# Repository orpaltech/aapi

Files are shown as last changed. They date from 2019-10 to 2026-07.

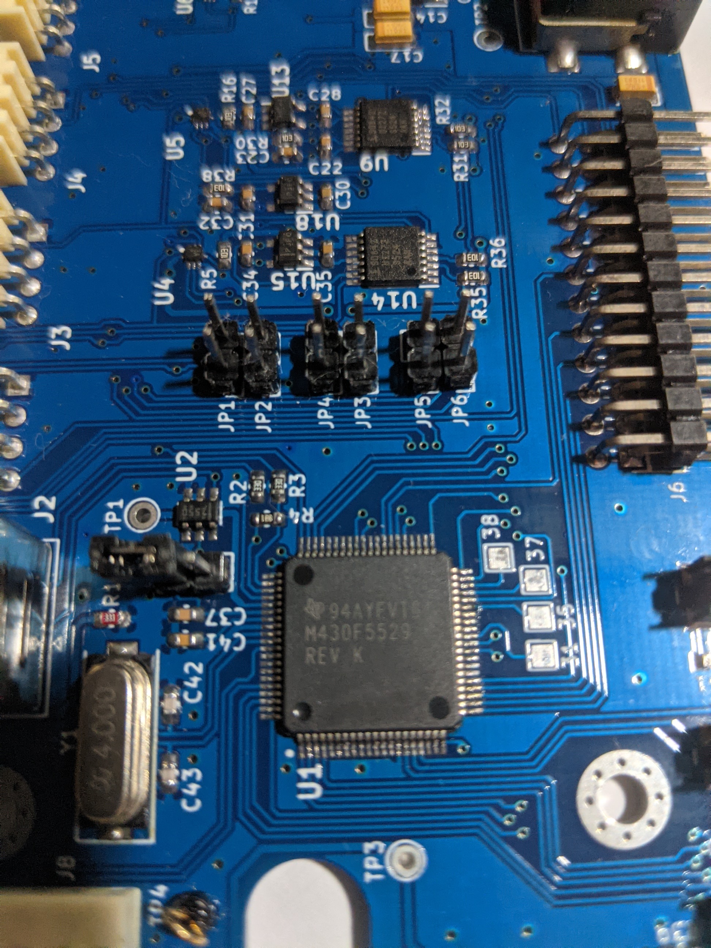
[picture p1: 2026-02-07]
hardware/images/EV2400/PXL_20260128_093434642.jpg

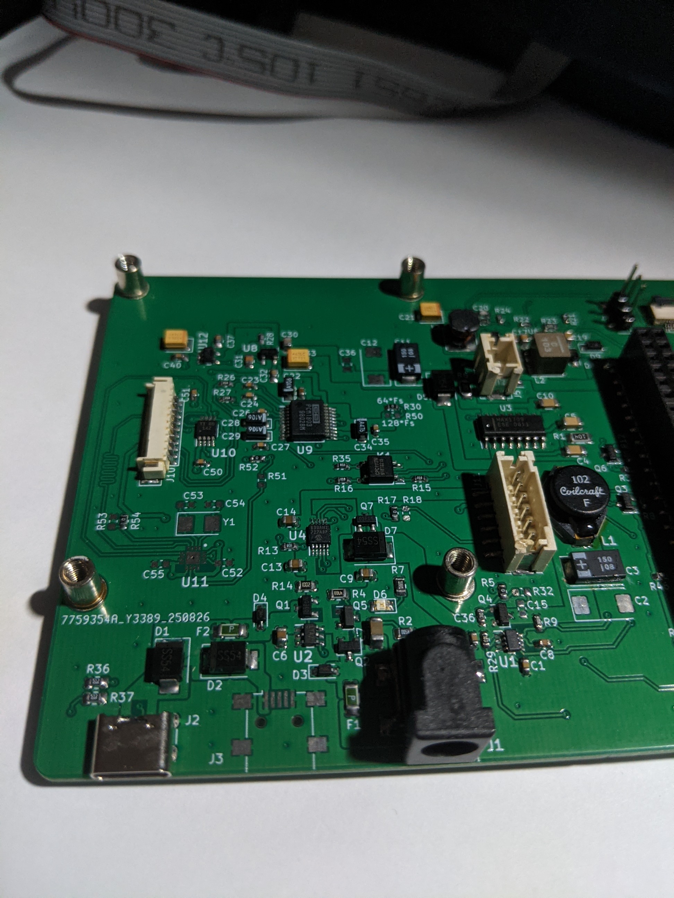
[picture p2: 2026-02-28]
hardware/images/v4.2/PXL_20260226_131540417.jpg

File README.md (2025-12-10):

ORPAL AA-PI
==============

Antenna analyzer project for portable Linux-based devices. 
The current hardware implementation is based on BananaPi M2-Magic SBC (Allwinner R16).

Version 4.3

Based on the Yuri Kuchura's EU1KY_AA_V3 https://github.com/EU1KY/eu1ky_aa_v3

Build
==============

The build process depends on the platform you have chosen. Currently the AA-PI software is managed by repository https://github.com/orpaltech/armlinux.

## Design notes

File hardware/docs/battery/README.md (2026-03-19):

# bq34z100-g1 + SN74HC164 Battery Gauge Setup

Hardware: 1S Li-ion (3800mAh), MCP73833 Charger (500/1000mA), 7-LED Display via Shift Register.

## 1. Initial Data Flash Configuration
Before starting, set these key parameters in **bqStudio**:

### 7-LED Display (SN74HC164)
*   **LED_Comm Configuration**: `0x63` (7 LEDs, Port Expander Mode, Button Trigger).
*   **Number of LEDs**: `7` (Verify in Configuration subclass).
*   **LED Hold Time**: `4` seconds.

### Gauge Thresholds
*   **Design Capacity**: `3800` mAh
*   **Design Energy**: `14060` mWh (3.7V * 3800)
*   **Taper Current**: `85` mA (Safe for 500mA/1000mA charging modes).
*   **Quit Current**: `20` mA (Must be lower than Taper).
*   **Dsg Relax Time**: `60` s (Speeds up OCV detection).
*   **Terminate Voltage**: `3200` mV (Set ~100mV above SBC/Boost cutoff).

## 2. Chemistry ID (GPCCHEM)
Do not use generic IDs. Follow this log sequence for the TI matching tool:
1.  Charge to full (Wait for **FC** bit).
2.  Rest **2 hours** (Wait for **OCVTAKEN=1**).
3.  Discharge at **C/10** (approx. 380mA - 500mA, I used Raspberry Pi 3 A+ with ESP32 HostedNG) until **Terminate Voltage**.
4.  Rest **5 hours** (Wait for **OCVTAKEN=1**).
5.  Zip the log and upload to [TI GPC Tool](https://www.ti.com). Program the resulting ID (e.g., `0x3230`) into the gauge.

## 3. Calibration
*   **Voltage**: Calibrate against a high-quality multimeter (Crucial for Qmax accuracy).
*   **Current**: Calibrate with a known stable load (e.g., 500mA).
*   **Temperature**: Set **TEMPS bit = 1** (External) for NTC thermistor.

## 4. The Learning Cycle (04 -> 05 -> 06)
1.  **IT_ENABLE**: Send command `0x0021`. **Update Status** should be `04`.
2.  **Empty Rest**: Wait at 0mA until **OCVTAKEN=1**.
3.  **Charge to Full**: Charge until **FC** bit is Red.
4.  **Full Rest**: Unplug charger. Wait **2 hours** until **OCVTAKEN=1**.
5.  **Discharge**: Run SBC load (500-600mA) until it shuts down.
6.  **Final Rest**: Wait **5 hours**.
    *   **Update Status 05**: Qmax updated.
    *   **Update Status 06**: Ra Table (Resistance) updated.

## 5. Troubleshooting
*   **OCVTAKEN won't set?** Check that **Current** is exactly `0mA`. If it flickers, re-calibrate CC Offset.
*   **Qmax too high?** Usually caused by starting a cycle on a non-rested battery or poor voltage calibration. Manually reset Qmax to 3800 and Update Status to 04 if it drifts.
*   **LEDs don't light?** Check wiring to SDA/SCL and ensure **VEN** pin is pulsed to Ground.

## 6. Dynamic Rebound Handling
To prevent the Learning Cycle from failing due to voltage rebound, use Cell Terminate Voltage (e.g., 3400mV) combined with Cell Term V Delta (e.g., 200mV). This creates a "Resting Empty" window (up to 3600mV) that accounts for the battery's natural spring-back after the SBC load is removed.

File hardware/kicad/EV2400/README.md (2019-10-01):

This is my implementation of the Texas Instruments EV2400 Interface board. The board datasheet is located here http://www.ti.com/lit/ug/sluu446c/sluu446c.pdf

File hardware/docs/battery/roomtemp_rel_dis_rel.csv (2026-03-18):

Sample | DateTime | ElapsedTime | Voltage | Current | Temperature | LogRowTime(ms) | LogStatus
1 | 2025-05-29 02:36:37 | 10.000 | 4189 | 0 | 27.0 | 46 | SUCCESS
2 | 2025-05-29 02:36:48 | 21.349 | 4189 | 0 | 27.0 | 39 | SUCCESS
3 | 2025-05-29 02:36:57 | 30.001 | 4189 | 0 | 27.0 | 44 | SUCCESS
4 | 2025-05-29 02:37:08 | 41.346 | 4189 | 0 | 27.0 | 45 | SUCCESS
5 | 2025-05-29 02:37:17 | 50.001 | 4189 | 0 | 27.0 | 44 | SUCCESS
6 | 2025-05-29 02:37:28 | 61.345 | 4189 | 0 | 27.0 | 44 | SUCCESS
7 | 2025-05-29 02:37:37 | 70.003 | 4189 | 0 | 27.0 | 42 | SUCCESS
8 | 2025-05-29 02:37:48 | 81.345 | 4189 | 0 | 27.0 | 44 | SUCCESS
9 | 2025-05-29 02:37:57 | 90.004 | 4189 | 0 | 27.0 | 44 | SUCCESS
10 | 2025-05-29 02:38:08 | 101.361 | 4189 | 0 | 27.0 | 46 | SUCCESS
11 | 2025-05-29 02:38:17 | 110.005 | 4189 | 0 | 27.0 | 41 | SUCCESS
12 | 2025-05-29 02:38:28 | 121.377 | 4189 | 0 | 27.0 | 44 | SUCCESS
13 | 2025-05-29 02:38:37 | 130.006 | 4189 | 0 | 27.0 | 40 | SUCCESS
14 | 2025-05-29 02:38:48 | 141.361 | 4189 | 0 | 27.0 | 46 | SUCCESS
15 | 2025-05-29 02:38:57 | 150.007 | 4189 | 0 | 27.0 | 40 | SUCCESS
16 | 2025-05-29 02:39:08 | 161.362 | 4189 | 0 | 27.0 | 44 | SUCCESS
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

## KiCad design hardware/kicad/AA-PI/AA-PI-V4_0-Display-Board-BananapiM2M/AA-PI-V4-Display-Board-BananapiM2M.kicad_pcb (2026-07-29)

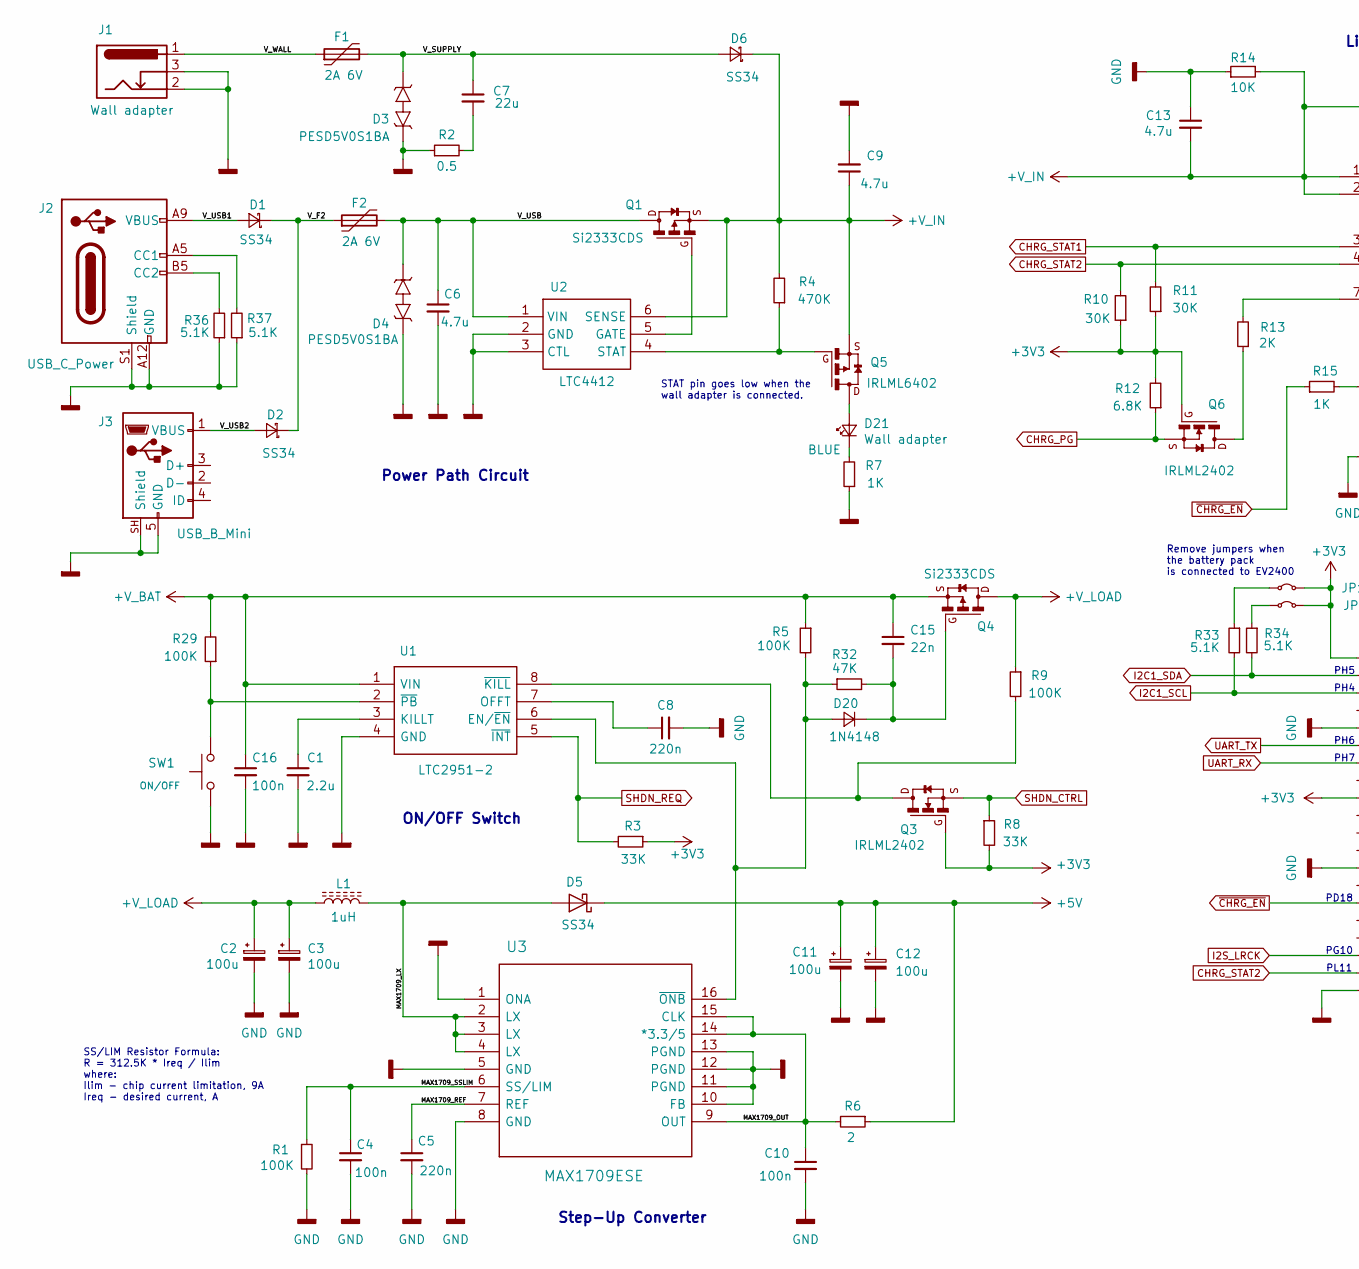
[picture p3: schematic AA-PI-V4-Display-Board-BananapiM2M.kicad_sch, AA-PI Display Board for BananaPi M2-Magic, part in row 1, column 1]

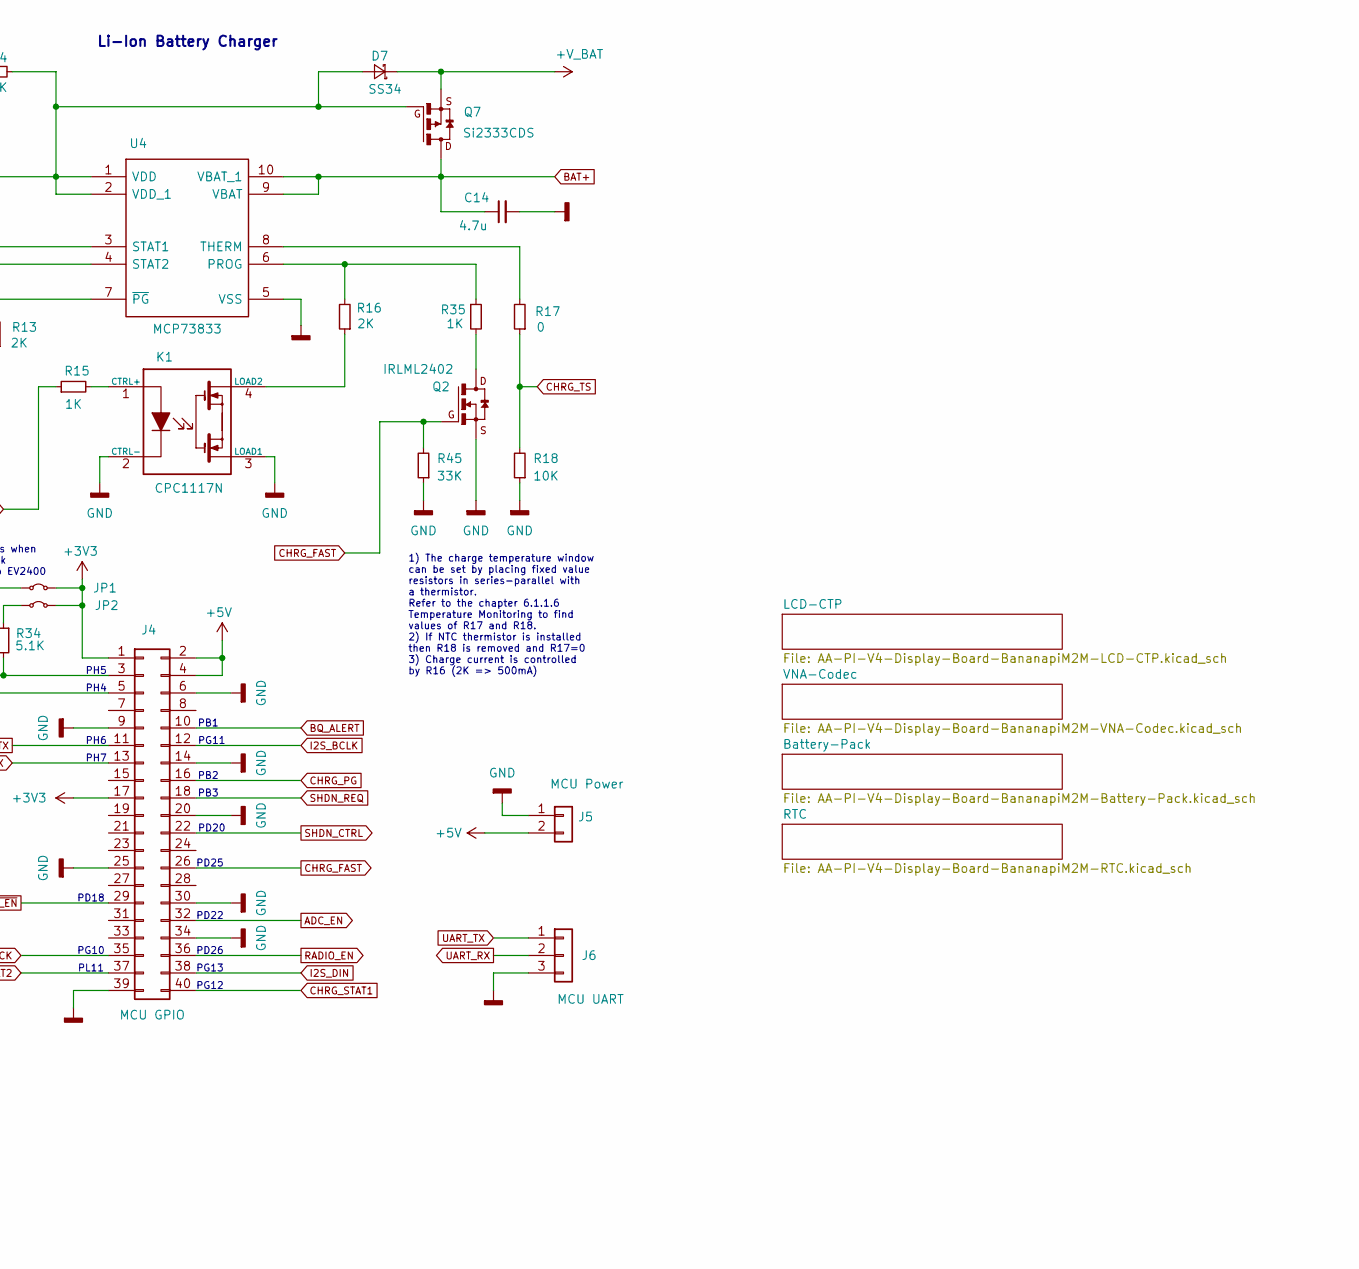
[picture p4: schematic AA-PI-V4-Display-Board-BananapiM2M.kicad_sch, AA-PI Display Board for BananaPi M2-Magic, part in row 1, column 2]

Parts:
C1: 2.2u; C_0603_1608Metric
C2, C3, C11, C12: 100u; CP_EIA-7343-31_Kemet-D
C4, C10: 100n; C_1206_3216Metric
C5: 220n; C_1206_3216Metric
C6, C9, C13, C14: 4.7u; C_0805_2012Metric
C7: 22u; C_1206_3216Metric
C8: 220n; C_0603_1608Metric
C15: 22n; C_0603_1608Metric
C16: 100n; C_0603_1608Metric
D1, D2, D5, D6, D7: SS34; D_SMA
D3, D4: PESD5V0S1BA; D_SOD-323_HandSoldering
D20: 1N4148; D_SOD-323_HandSoldering
D21: Wall adapter; LED_0805_2012Metric_Pad1.15x1.40mm_HandSolder
F1, F2: 2A 6V; Fuse_1206_3216Metric_Pad1.42x1.75mm_HandSolder
J1: Wall adapter; DC-050-SMD-Power-Jack
J2: USB_C_Power; USB_C_Receptacle_GCT_USB4125-xx-x_6P_TopMnt_Horizontal
J3: USB_B_Mini; USB_Mini-B_Lumberg_2486_01_Horizontal
J4: MCU GPIO; PinSocket_2x20_P2.54mm_Vertical_SMD
J5: MCU Power; JST_PH_B2B-PH-SM4-TB_1x02-1MP_P2.00mm_Vertical
J6: MCU UART; PinHeader_1x03_P2.54mm_Vertical_SMD_Pin1Left
JP1, JP2: Jumper_2_Small_Bridged; PinHeader_2x01_P2.00mm_Vertical_SMD
K1: CPC1117N; SOP254P610X218-4N; Manufacturer_Part_Number CPC1117N
L1: 1uH; COILCRAFT_DO3316P102MLB
Q1, Q4, Q7: Si2333CDS; SOT-23
Q2, Q3, Q6: IRLML2402; SOT-23
Q5: IRLML6402; SOT-23
R1: 100K; R_1206_3216Metric
R2: 0.5; R_0805_2012Metric
R3, R8, R45: 33K; R_0603_1608Metric
R4: 470K; R_0805_2012Metric
R5, R9, R29: 100K; R_0603_1608Metric
R6: 2; R_1206_3216Metric
R7: 1K; R_0805_2012Metric
R10, R11: 30K; R_0603_1608Metric
R12: 6.8K; R_0603_1608Metric
R13, R16: 2K; R_0603_1608Metric
R14: 10K; R_0805_2012Metric
R15, R35: 1K; R_0603_1608Metric
R17: 0; R_0603_1608Metric
R18: 10K; R_0603_1608Metric
R32: 47K; R_0603_1608Metric
R33, R34: 5.1K; R_0603_1608Metric
R36, R37: 5.1K; R_0805_2012Metric
SW1: ON/OFF; SW_SPST_CK_RS282G05A3
U1: LTC2951-2; SOT65P280X100-8N; Manufacturer_Part_Number LTC2951CTS8-1#TRMPBF
U2: LTC4412; SOT95P280X100-6N; Manufacturer_Part_Number LTC4412ES6#TRMPBF
U3: MAX1709ESE; SOIC-16_3.9x9.9mm_P1.27mm
U4: MCP73833; SOP50P490X110-10N; Manufacturer_Part_Number MCP73833-FCI/UN

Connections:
+3V3: J4.1, J4.17, JP1.2 (B), JP2.2 (B), Q3.1 (G), Q6.1 (G), R3.1, R8.2, R10.1, R11.1, R12.2; also elsewhere on the board
+5V: C11.1, C12.1, D5.1 (K), J4.2, J4.4, J5.2, R6.1; also elsewhere on the board
+V_BAT: C15.1, C16.1, D7.1 (K), Q4.2 (S), Q7.2 (S), R5.1, R29.2, U1.1 (VIN)
+V_IN: C9.1, C13.2, D6.1 (K), D7.2 (A), Q1.2 (S), Q5.2 (S), Q7.1 (G), R4.2, R14.2, U2.6 (SENSE), U4.1 (VDD), U4.2 (VDD_1)
+V_LOAD: C2.1, C3.1, L1.1, Q4.3 (D), R9.1
/MAX1709_LX: D5.2 (A), L1.2, U3.2 (LX), U3.3 (LX), U3.4 (LX)
/MAX1709_OUT: C10.1, R6.2, U3.9 (OUT), U3.14 (*3.3/5), U3.15 (CLK)
/MAX1709_REF: C5.1, U3.7 (REF)
/MAX1709_SSLIM: C4.1, R1.1, U3.6 (SS/LIM)
/V_F2: D1.1 (K), D2.1 (K), F2.1
/V_SUPPLY: C7.1, D3.2, D6.2 (A), F1.2
/V_USB: C6.1, D4.2, F2.2, Q1.3 (D), U2.1 (VIN)
/V_USB1: D1.2 (A), J2.A9 (VBUS), J2.B9 (VBUS)
/V_USB2: D2.2 (A), J3.1 (VBUS)
/V_WALL: F1.1, J1.1
ADC_EN: J4.32; also elsewhere on the board
BAT+: C14.1, Q7.3 (D), U4.9 (VBAT), U4.10 (VBAT_1); also elsewhere on the board
BQ_ALERT: J4.10; also elsewhere on the board
CHRG_FAST: J4.26, Q2.1 (G), R45.2
CHRG_PG: J4.16, Q6.2 (S), R12.1
CHRG_STAT1: J4.40, R11.2, U4.3 (STAT1)
CHRG_STAT2: J4.37, R10.2, U4.4 (STAT2)
CHRG_TS: R17.1, R18.2; also elsewhere on the board
GND: C1.2, C2.2, C3.2, C4.2, C5.2, C6.2, C8.2, C9.2, C10.2, C11.2, C12.2, C13.1, C14.2, C16.2, D3.1, D4.1, J1.2, J1.3, J2.A12 (GND), J2.B12 (GND), J2.S1 (Shield), J3.5 (GND), J3.SH (Shield), J4.6, J4.9, J4.14, J4.20, J4.25, J4.30, J4.34, J4.39, J5.1, J6.3, K1.2 (CTRL-), K1.3 (LOAD1), Q2.2 (S), R1.2, R2.1, R7.1, R14.1, R18.1, R36.1, R37.1, R45.1, SW1.1, U1.4 (GND), U2.2 (GND), U2.3 (CTL), U3.1 (ONA), U3.5 (GND), U3.8 (GND), U3.10 (FB), U3.11 (PGND), U3.12 (PGND), U3.13 (PGND), U4.5 (VSS); also elsewhere on the board
I2C1_SCL: J4.5, R33.2; also elsewhere on the board
I2C1_SDA: J4.3, R34.2; also elsewhere on the board
I2S_BCLK: J4.12; also elsewhere on the board
I2S_DIN: J4.38; also elsewhere on the board
I2S_LRCK: J4.35; also elsewhere on the board
unnamed: C7.2, R2.2
unnamed: D20.2 (A), R5.2, R32.1, U1.6 (EN/~EN), U3.16 (~ONB)
unnamed: C15.2, D20.1 (K), Q4.1 (G), R32.2
unnamed: D21.2 (A), Q5.3 (D)
unnamed: D21.1 (K), R7.2
unnamed: J2.A5 (CC1), R37.2
unnamed: J2.B5 (CC2), R36.2
unnamed: JP1.1 (A), R33.1
unnamed: JP2.1 (A), R34.1
unnamed: K1.1 (CTRL+), R15.2
unnamed: K1.4 (LOAD2), R16.1
unnamed: Q1.1 (G), U2.5 (GATE)
unnamed: Q2.3 (D), R35.2
unnamed: Q3.3 (D), R9.2, U1.8 (~KILL)
unnamed: Q5.1 (G), R4.1, U2.4 (STAT)
unnamed: Q6.3 (D), R13.1
unnamed: C1.1, U1.3 (KILLT)
unnamed: C8.1, U1.7 (OFFT)
unnamed: R29.1, SW1.2, U1.2 (~PB)
unnamed: R16.2, R35.1, U4.6 (PROG)
unnamed: R17.2, U4.8 (THERM)
unnamed: R13.2, U4.7 (~PG)
RADIO_EN: J4.36; also elsewhere on the board
SHDN_CTRL: J4.22, Q3.2 (S), R8.1
SHDN_REQ: J4.18, R3.2, U1.5 (~INT)
UART_RX: J4.13, J6.2
UART_TX: J4.11, J6.1
~CHRG_EN: J4.29, R15.1

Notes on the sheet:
PH4
PD26
SS/LIM Resistor Formula: R = 312.5K * Ireq / Ilim where: Ilim - chip current limitation, 9A Ireq - desired current, A
STAT pin goes low when the wall adapter is connected.
PD20
PG12
PG10
PB1
PB3
Power Path Circuit
1) The charge temperature window can be set by placing fixed value resistors in series-parallel with a thermistor. Refer to the chapter 6.1.1.6 Temperature Monitoring to find values of R17 and R18. 2) If NTC thermistor is installed then R18 is removed and R17=0 3) Charge current is controlled by R1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
PG11
Step-Up Converter
PH6
ON/OFF Switch
PH7
PB2
Remove jumpers when the battery pack is connected to EV2400
PD18
PG13
PD25
PH5
PD22
Li-Ion Battery Charger
PL11

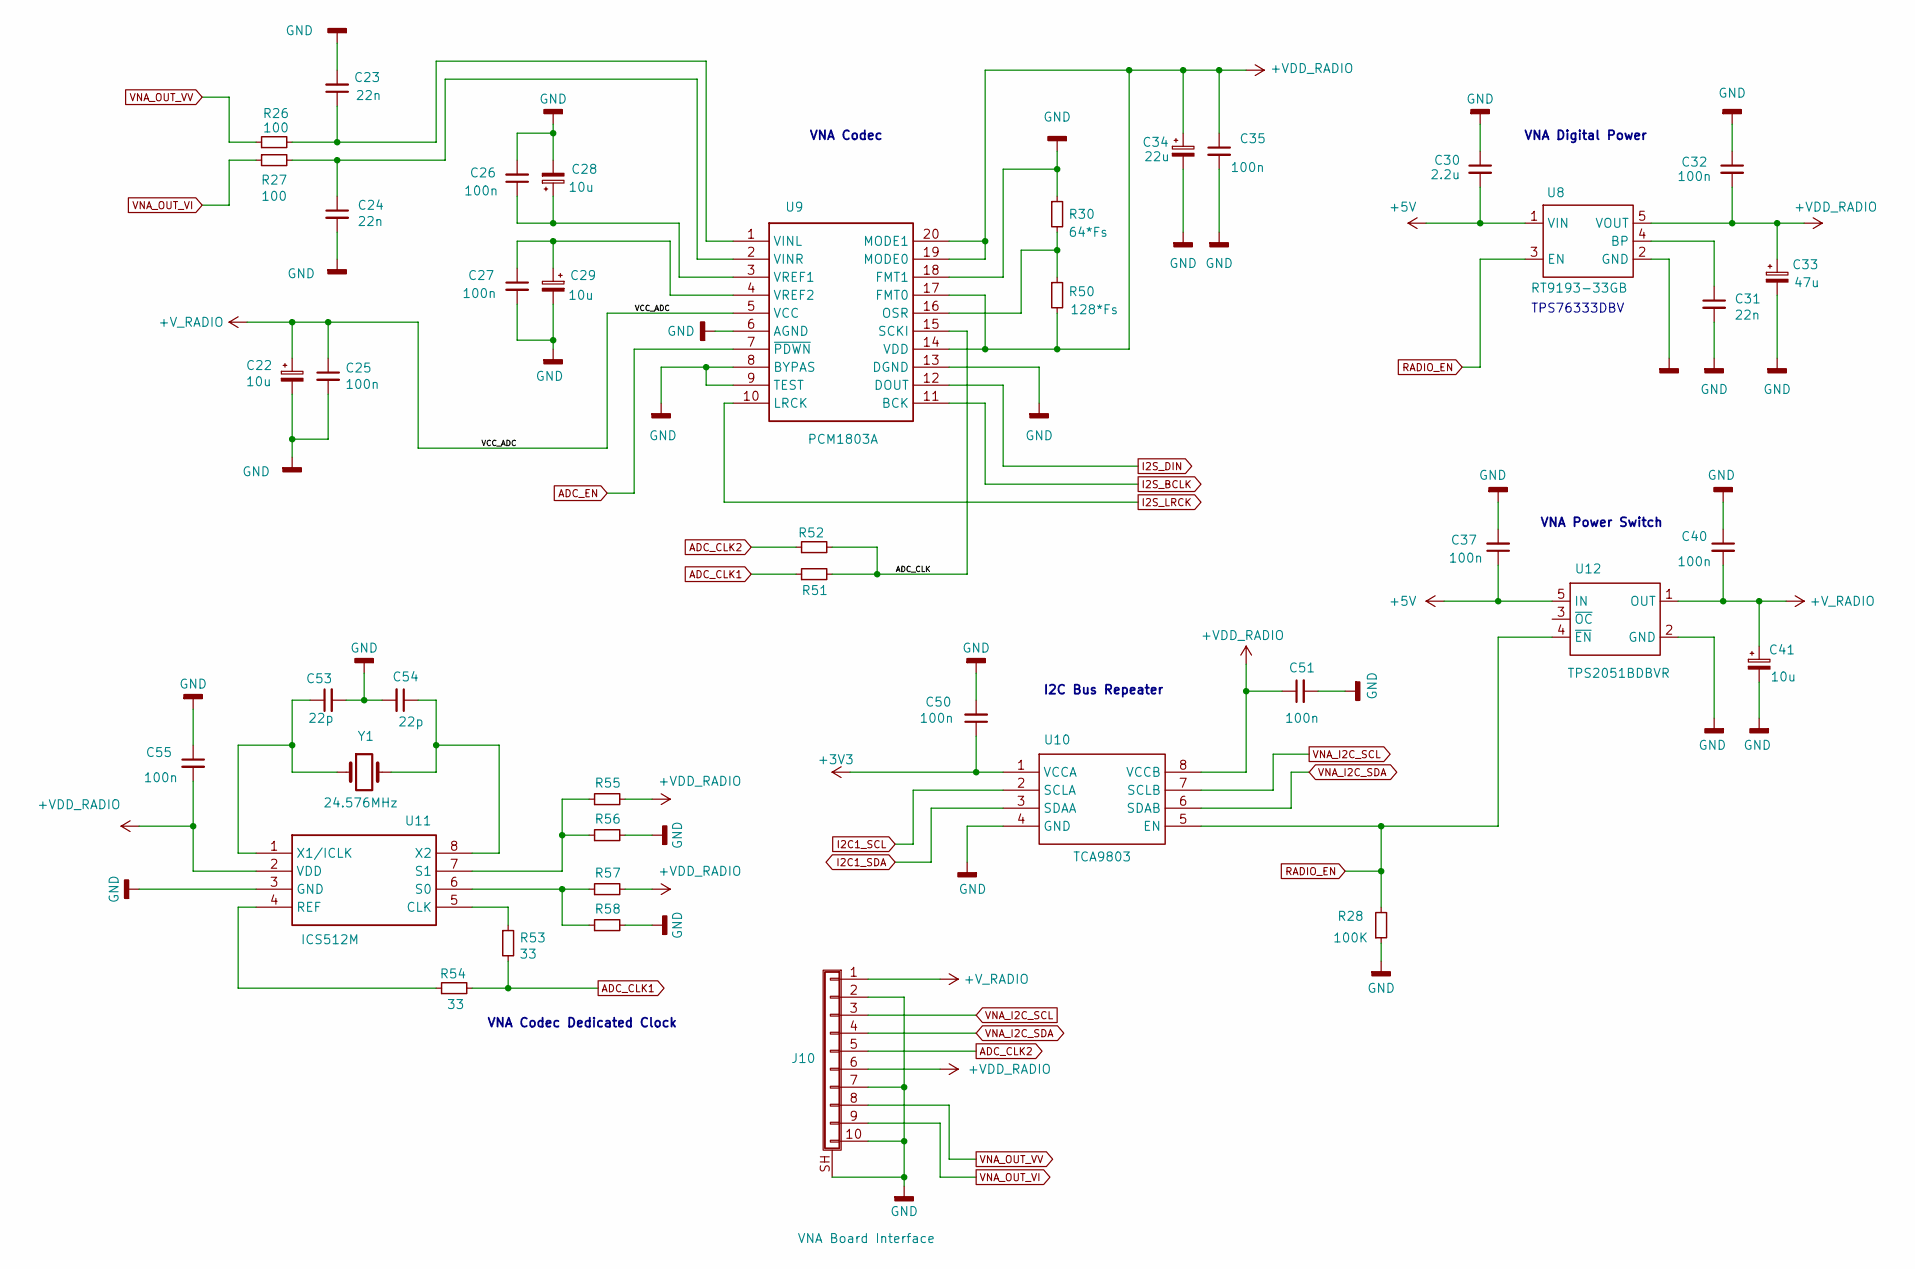
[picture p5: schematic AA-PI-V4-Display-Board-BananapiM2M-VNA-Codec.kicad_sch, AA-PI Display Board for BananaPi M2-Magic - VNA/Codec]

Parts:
C22, C28, C29: 10u; CP_EIA-3216-18_Kemet-A
C23, C24: 22n; C_0603_1608Metric
C25, C26, C27, C35, C50, C51, C55: 100n; C_0603_1608Metric
C30: 2.2u; C_0805_2012Metric_Pad1.15x1.40mm_HandSolder
C31: 22n; C_0805_2012Metric
C32, C37, C40: 100n; C_0805_2012Metric
C33: 47u; CP_EIA-3528-21_Kemet-B
C34: 22u; CP_EIA-3216-18_Kemet-A
C41: 10u; CP_EIA-3528-21_Kemet-B
C53, C54: 22p; C_0603_1608Metric
J10: VNA Board Interface; 1.25-AB-SMT-10pin-Vertical
R26, R27: 100; R_0603_1608Metric
R28: 100K; R_0603_1608Metric
R30: 64*Fs; R_0603_1608Metric
R50: 128*Fs; R_0603_1608Metric
R51, R52, R55, R56, R57, R58: 0; R_0603_1608Metric
R53, R54: 33; R_0603_1608Metric
U8: RT9193-33GB; SOT94P279X130-5N; Manufacturer_Part_Number RT9193
U9: PCM1803A; SOP65P780X200-20N; Manufacturer_Part_Number PCM1803DBR; Mouser Part Number 595-PCM1803DBR
U10: TCA9803; SOP65P490X110-8N; Manufacturer_Part_Number TCA9802DGKR
U11: ICS512M; SOIC127P600X175-8N; Manufacturer_Part_Number ICS512MILF
U12: TPS2051BDBVR; SOT95P280X145-5N; Manufacturer_Part_Number TPS2051BDBVR
Y1: 24.576MHz; Crystal_SMD_5032-2Pin_5.0x3.2mm

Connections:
+3V3: C50.1, U10.1 (VCCA); also elsewhere on the board
+5V: C30.2, C37.1, U8.1 (VIN), U12.5 (IN); also elsewhere on the board
+VDD_RADIO: C32.2, C33.1, C34.1, C35.1, C51.1, C55.2, J10.6, R50.2, R55.2, R57.2, U8.5 (VOUT), U9.14 (VDD), U9.17 (FMT0), U9.19 (MODE0), U9.20 (MODE1), U10.8 (VCCB), U11.2 (VDD)
+V_RADIO: C22.1, C25.1, C40.2, C41.1, J10.1, U9.5 (VCC), U12.1 (OUT)
/VNA-Codec/ADC_CLK: R51.2, R52.2, U9.15 (SCKI)
ADC_CLK1: R51.1, R53.2, R54.2
ADC_CLK2: J10.5, R52.1
ADC_EN: U9.7 (~PDWN); also elsewhere on the board
GND: C22.2, C23.2, C24.2, C25.2, C26.2, C27.2, C28.2, C29.2, C30.1, C31.2, C32.1, C33.2, C34.2, C35.2, C37.2, C40.1, C41.2, C50.2, C51.2, C53.2, C54.2, C55.1, J10.2, J10.7, J10.10, J10.SH (Shield), R28.1, R30.1, R56.2, R58.2, U8.2 (GND), U9.6 (AGND), U9.8 (BYPAS), U9.9 (TEST), U9.13 (DGND), U9.18 (FMT1), U10.4 (GND), U11.3 (GND), U12.2 (GND); also elsewhere on the board
I2C1_SCL: U10.2 (SCLA); also elsewhere on the board
I2C1_SDA: U10.3 (SDAA); also elsewhere on the board
I2S_BCLK: U9.11 (BCK); also elsewhere on the board
I2S_DIN: U9.12 (DOUT); also elsewhere on the board
I2S_LRCK: U9.10 (LRCK); also elsewhere on the board
unnamed: C31.1, U8.4 (BP)
unnamed: R30.2, R50.1, U9.16 (OSR)
unnamed: C23.1, R26.2, U9.1 (VINL)
unnamed: C24.1, R27.2, U9.2 (VINR)
unnamed: C26.1, C28.1, U9.3 (VREF1)
unnamed: C27.1, C29.1, U9.4 (VREF2)
unnamed: R53.1, U11.5 (CLK)
unnamed: R54.1, U11.4 (REF)
unnamed: R57.1, R58.1, U11.6 (S0)
unnamed: R55.1, R56.1, U11.7 (S1)
unnamed: C53.1, U11.1 (X1/ICLK), Y1.1
unnamed: C54.1, U11.8 (X2), Y1.2
RADIO_EN: R28.2, U8.3 (EN), U10.5 (EN), U12.4 (~EN); also elsewhere on the board
VNA_I2C_SCL: J10.3, U10.7 (SCLB)
VNA_I2C_SDA: J10.4, U10.6 (SDAB)
VNA_OUT_VI: J10.9, R27.1
VNA_OUT_VV: J10.8, R26.1

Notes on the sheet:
VNA Power Switch
VNA Codec
VNA Codec Dedicated Clock
I2C Bus Repeater
TPS76333DBV
VNA Digital Power

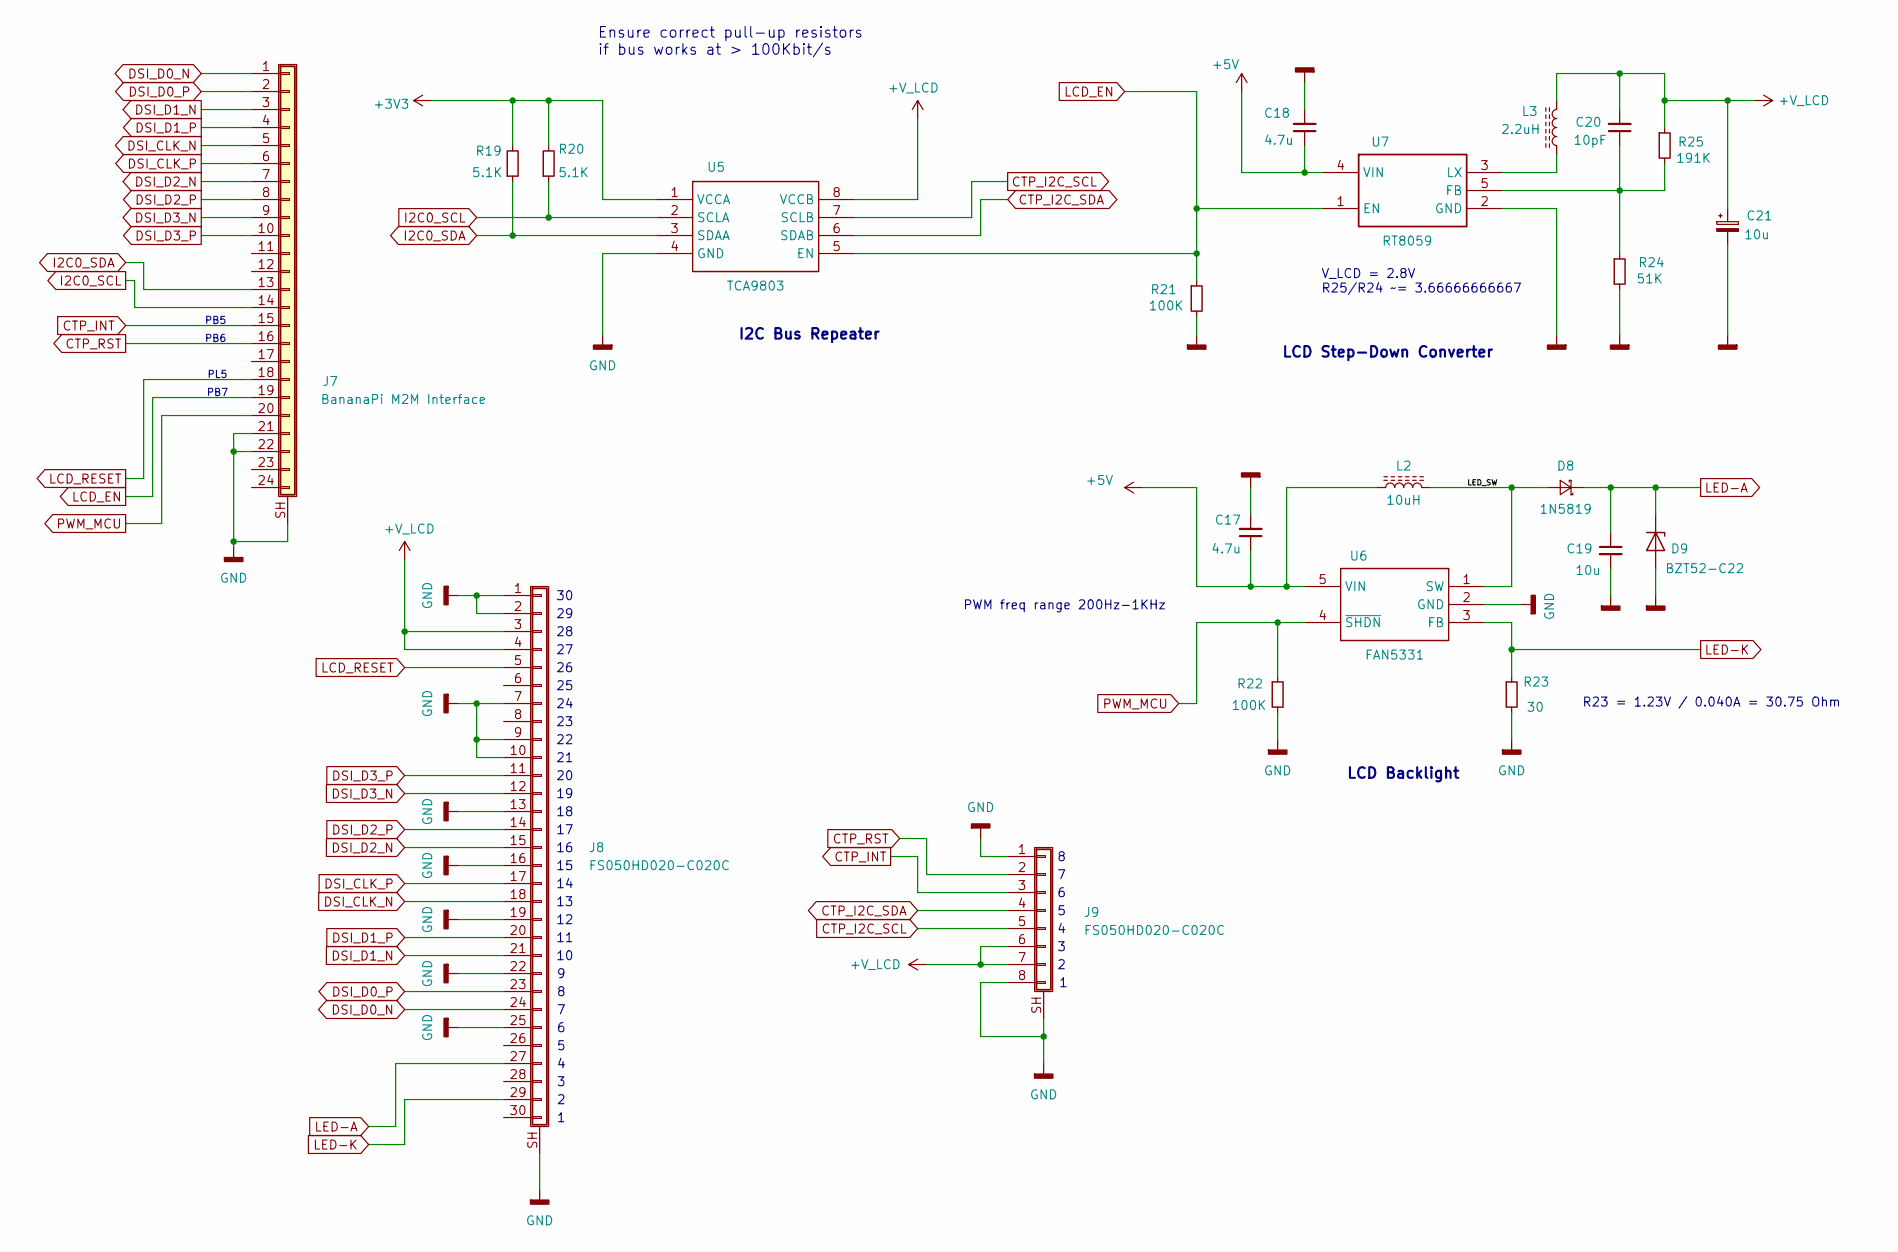
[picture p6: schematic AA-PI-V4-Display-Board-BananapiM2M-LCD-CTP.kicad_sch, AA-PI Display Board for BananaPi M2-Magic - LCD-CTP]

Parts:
C17, C18: 4.7u; C_0805_2012Metric
C19: 10u; C_0805_2012Metric
C20: 10pF; C_0805_2012Metric
C21: 10u; CP_EIA-3528-21_Kemet-B
D8: 1N5819; D_SOD-123
D9: BZT52-C22; D_SOD-123
J7: BananaPi M2M Interface; FPC-0.5-1-24P_CLAMSH_BTM
J8: FS050HD020-C020C; FPC-0.5-1-30P_Clamshell_Bottom
J9: FS050HD020-C020C; FPC-0.5-1-8P_Clamshell_Bottom
L2: 10uH; COILCRAFT_XEL5050_HandSolder
L3: 2.2uH; COILCRAFT_XEL5050_HandSolder
R19, R20: 5.1K; R_0603_1608Metric
R21, R22: 100K; R_0603_1608Metric
R23: 30; R_0805_2012Metric
R24: 51K; R_0603_1608Metric
R25: 191K; R_0603_1608Metric
U5: TCA9803; SOP65P490X110-8N; Manufacturer_Part_Number TCA9802DGKR
U6: FAN5331; SOT95P270X145-5N; Manufacturer_Part_Number FAN5333BSX
U7: RT8059; SOT94P280X100-5N; Manufacturer_Part_Number RT8059GJ5; Mouser Part Number 835-RT8059GJ5

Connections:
+3V3: R19.2, R20.2, U5.1 (VCCA); also elsewhere on the board
+5V: C17.1, C18.1, L2.1, U6.5 (VIN), U7.4 (VIN); also elsewhere on the board
+V_LCD: C20.2, C21.1, J8.3, J8.4, J9.6, J9.7, L3.2, R25.1, U5.8 (VCCB)
/LCD-CTP/LED_SW: D8.2 (A), L2.2, U6.1 (SW)
CTP_I2C_SCL: J9.5, U5.7 (SCLB)
CTP_I2C_SDA: J9.4, U5.6 (SDAB)
CTP_INT: J7.15, J9.3
CTP_RST: J7.16, J9.2
DSI_CLK_N: J7.5, J8.18
DSI_CLK_P: J7.6, J8.17
DSI_D0_N: J7.1, J8.24
DSI_D0_P: J7.2, J8.23
DSI_D1_N: J7.3, J8.21
DSI_D1_P: J7.4, J8.20
DSI_D2_N: J7.7, J8.15
DSI_D2_P: J7.8, J8.14
DSI_D3_N: J7.9, J8.12
DSI_D3_P: J7.10, J8.11
GND: C17.2, C18.2, C19.2, C21.2, D9.2 (A), J7.21, J7.22, J7.SH (Shield), J8.1, J8.2, J8.7, J8.9, J8.10, J8.13, J8.16, J8.19, J8.22, J8.25, J8.SH (Shield), J9.1, J9.8, J9.SH (Shield), R21.2, R22.2, R23.2, R24.2, U5.4 (GND), U6.2 (GND), U7.2 (GND); also elsewhere on the board
I2C0_SCL: J7.14, R20.1, U5.2 (SCLA)
I2C0_SDA: J7.13, R19.1, U5.3 (SDAA)
LCD_EN: J7.19, R21.1, U5.5 (EN), U7.1 (EN)
LCD_RESET: J7.18, J8.5
LED-A: C19.1, D8.1 (K), D9.1 (K), J8.27
LED-K: J8.29, R23.1, U6.3 (FB)
unnamed: C20.1, R24.1, R25.2, U7.5 (FB)
unnamed: L3.1, U7.3 (LX)
PWM_MCU: J7.20, R22.1, U6.4 (~SHDN)

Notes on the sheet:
PB7
R23 = 1.23V / 0.040A = 30.75 Ohm
PB6
LCD Step-Down Converter
PWM freq range 200Hz-1KHz
I2C Bus Repeater
LCD Backlight
PB5
PL5
V_LCD = 2.8V R25/R24 ~= 3.66666666667
Ensure correct pull-up resistors if bus works at > 100Kbit/s

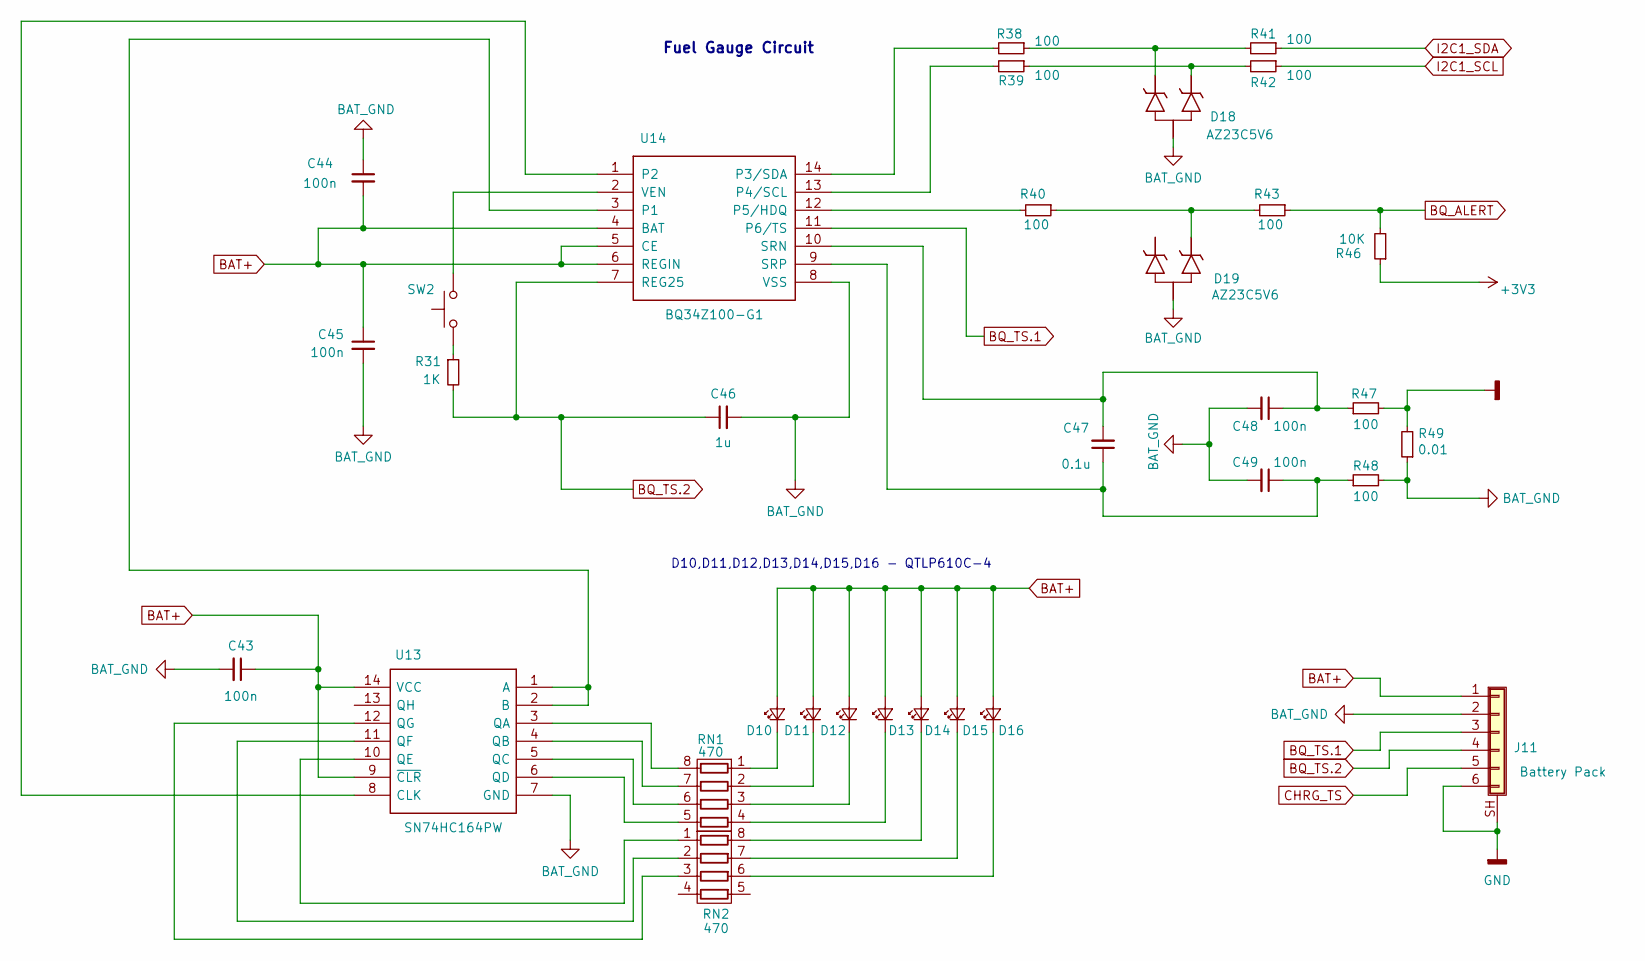
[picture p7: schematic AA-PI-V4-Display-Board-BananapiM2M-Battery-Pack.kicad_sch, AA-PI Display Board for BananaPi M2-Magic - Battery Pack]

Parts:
C43, C44, C45, C48, C49: 100n; C_0603_1608Metric
C46: 1u; C_0805_2012Metric_Pad1.15x1.40mm_HandSolder
C47: 0.1u; C_0603_1608Metric
D10, D11, D12, D13, D14, D15, D16: QTLP610C-4; QTLP610C4TR_2; Manufacturer_Part_Number QTLP610C4TR
D18, D19: AZ23C5V6; SOT96P240X110-3N; Manufacturer_Part_Number AZ23C2V7-AZ23C51
J11: Battery Pack; JST_PH_B6B-PH-SM4-TB_1x06-1MP_P2.00mm_Vertical
R31: 1K; R_0603_1608Metric
R38, R39, R40, R41, R42, R43, R47, R48: 100; R_0603_1608Metric
R46: 10K; R_0603_1608Metric
R49: 0.01; R_0805_2012Metric
RN1, RN2: 470; R_Array_Convex_4x0603
SW2: SW_Push; SW_SPST_3X4X2.5_SMD
U13: SN74HC164PW; SOP65P640X120-14N; Manufacturer_Part_Number SN74HC164PW
U14: BQ34Z100-G1; SOP65P640X120-14N; Manufacturer_Part_Number BQ34Z100PWR-G1

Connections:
+3V3: R46.1; also elsewhere on the board
BAT+: C43.1, C44.2, C45.1, D10.2 (A), D11.2 (A), D12.2 (A), D13.2 (A), D14.2 (A), D15.2 (A), D16.2 (A), J11.1, U13.9 (~CLR), U13.14 (VCC), U14.4 (BAT), U14.5 (CE), U14.6 (REGIN); also elsewhere on the board
BAT_GND: C43.2, C44.1, C45.2, C46.2, C48.2, C49.2, D18.3, D19.3, J11.2, R48.2, R49.1, U13.7 (GND), U14.8 (VSS)
BQ_ALERT: R43.1, R46.2; also elsewhere on the board
BQ_TS.1: J11.3, U14.11 (P6/TS)
BQ_TS.2: C46.1, J11.4, R31.2, U14.7 (REG25)
CHRG_TS: J11.5; also elsewhere on the board
GND: J11.6, J11.SH (Shield), R47.2, R49.2; also elsewhere on the board
I2C1_SCL: R42.1; also elsewhere on the board
I2C1_SDA: R41.1; also elsewhere on the board
unnamed: D10.1 (K), RN1.1 (R1.1)
unnamed: D11.1 (K), RN1.2 (R2.1)
unnamed: D12.1 (K), RN1.3 (R3.1)
unnamed: D13.1 (K), RN1.4 (R4.1)
unnamed: D14.1 (K), RN2.8 (R1.2)
unnamed: D15.1 (K), RN2.7 (R2.2)
unnamed: D16.1 (K), RN2.6 (R3.2)
unnamed: D18.1, R39.1, R42.2
unnamed: D18.2, R38.1, R41.2
unnamed: D19.1, R40.1, R43.2
unnamed: R31.1, SW2.1
unnamed: RN1.8 (R1.2), U13.3 (QA)
unnamed: RN1.7 (R2.2), U13.4 (QB)
unnamed: RN1.6 (R3.2), U13.5 (QC)
unnamed: RN1.5 (R4.2), U13.6 (QD)
unnamed: RN2.1 (R1.1), U13.10 (QE)
unnamed: RN2.2 (R2.1), U13.11 (QF)
unnamed: RN2.3 (R3.1), U13.12 (QG)
unnamed: U13.1 (A), U13.2 (B), U14.3 (P1)
unnamed: U13.8 (CLK), U14.1 (P2)
unnamed: R38.2, U14.14 (P3/SDA)
unnamed: R39.2, U14.13 (P4/SCL)
unnamed: R40.2, U14.12 (P5/HDQ)
unnamed: C47.2, C48.1, R47.1, U14.10 (SRN)
unnamed: C47.1, C49.1, R48.1, U14.9 (SRP)
unnamed: SW2.2, U14.2 (VEN)

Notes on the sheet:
D10,D11,D12,D13,D14,D15,D16 - QTLP610C-4
Fuel Gauge Circuit

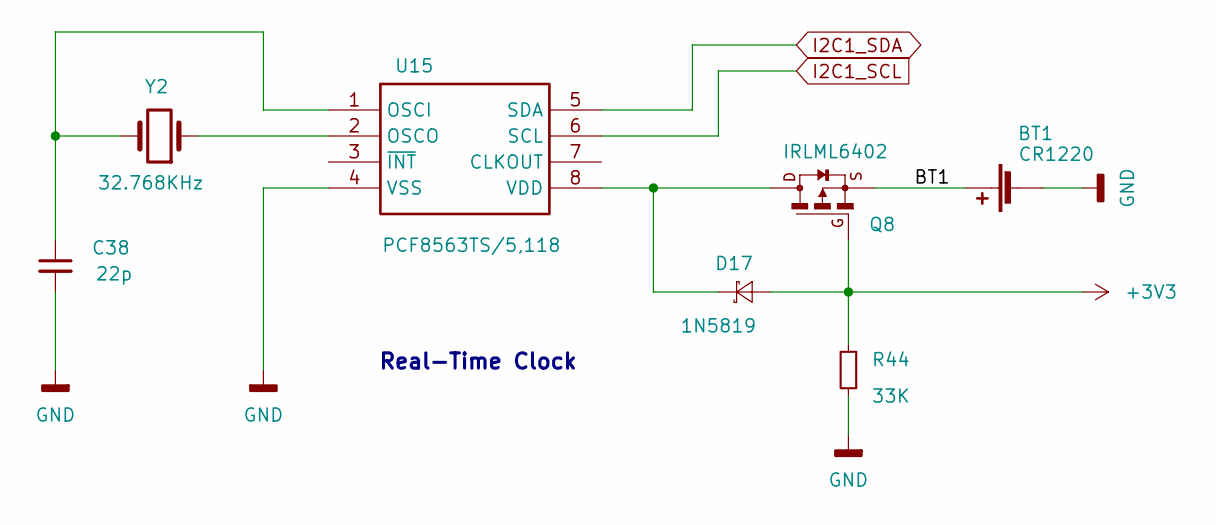
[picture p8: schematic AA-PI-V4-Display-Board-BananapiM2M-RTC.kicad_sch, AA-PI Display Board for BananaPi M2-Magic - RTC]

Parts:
BT1: CR1220; CR1220-2
C38: 22p; C_0603_1608Metric
D17: 1N5819; D_SOD-323_HandSoldering
Q8: IRLML6402; SOT-23
R44: 33K; R_0603_1608Metric
U15: PCF8563TS/5,118; SOT65P490X110-8N; Manufacturer_Part_Number PCF8563TS/5,118; Mouser Part Number 771-PCF8563TS/5118
Y2: 32.768KHz; Crystal_SMD_3215-2Pin_3.2x1.5mm

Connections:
+3V3: D17.2 (A), Q8.1 (G), R44.1; also elsewhere on the board
/RTC/BT1: BT1.1 (+), Q8.2 (S)
GND: BT1.2 (-), C38.2, R44.2, U15.4 (VSS); also elsewhere on the board
I2C1_SCL: U15.6 (SCL); also elsewhere on the board
I2C1_SDA: U15.5 (SDA); also elsewhere on the board
unnamed: D17.1 (K), Q8.3 (D), U15.8 (VDD)
unnamed: C38.1, U15.1 (OSCI), Y2.2
unnamed: U15.2 (OSCO), Y2.1

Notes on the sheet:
Real-Time Clock

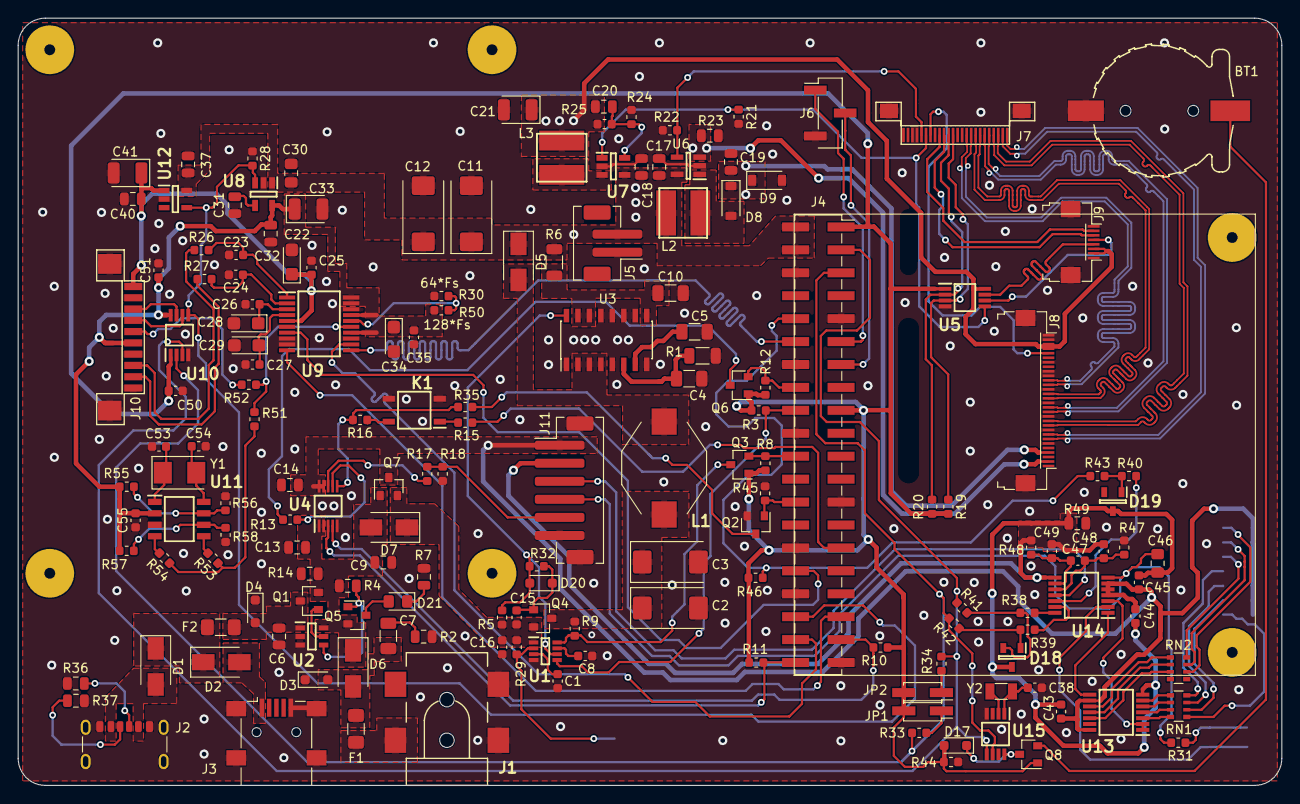
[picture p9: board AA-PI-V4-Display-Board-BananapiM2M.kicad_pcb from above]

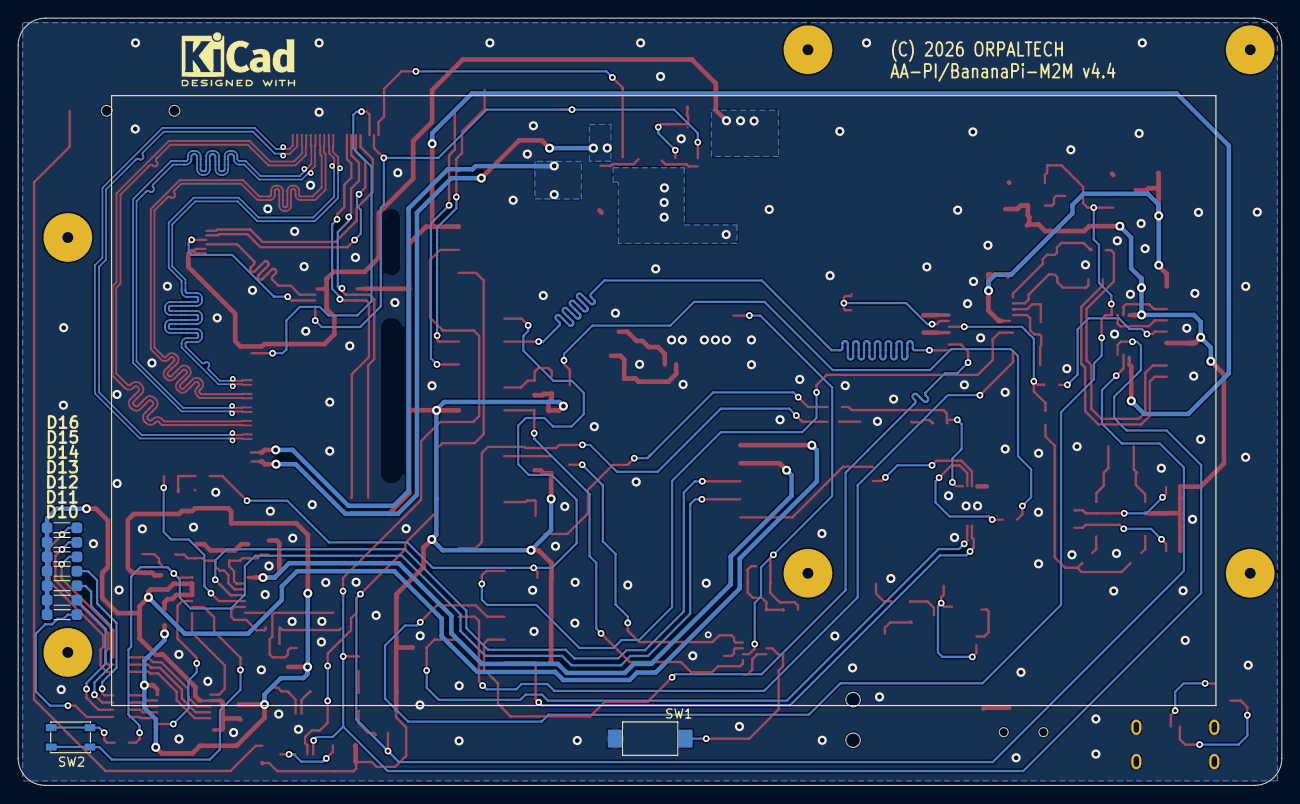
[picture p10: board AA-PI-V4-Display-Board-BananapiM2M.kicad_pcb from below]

Board: 2 copper layers, 140.0 x 85.0 mm, 186 parts (9 on the bottom side), 136 nets.

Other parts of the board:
CH1: CTP-CABLE-HOLE
SS2, SS4, SS5, SS6, SS7, SS8: PCB-Standoff-Spacer-SMD-M3

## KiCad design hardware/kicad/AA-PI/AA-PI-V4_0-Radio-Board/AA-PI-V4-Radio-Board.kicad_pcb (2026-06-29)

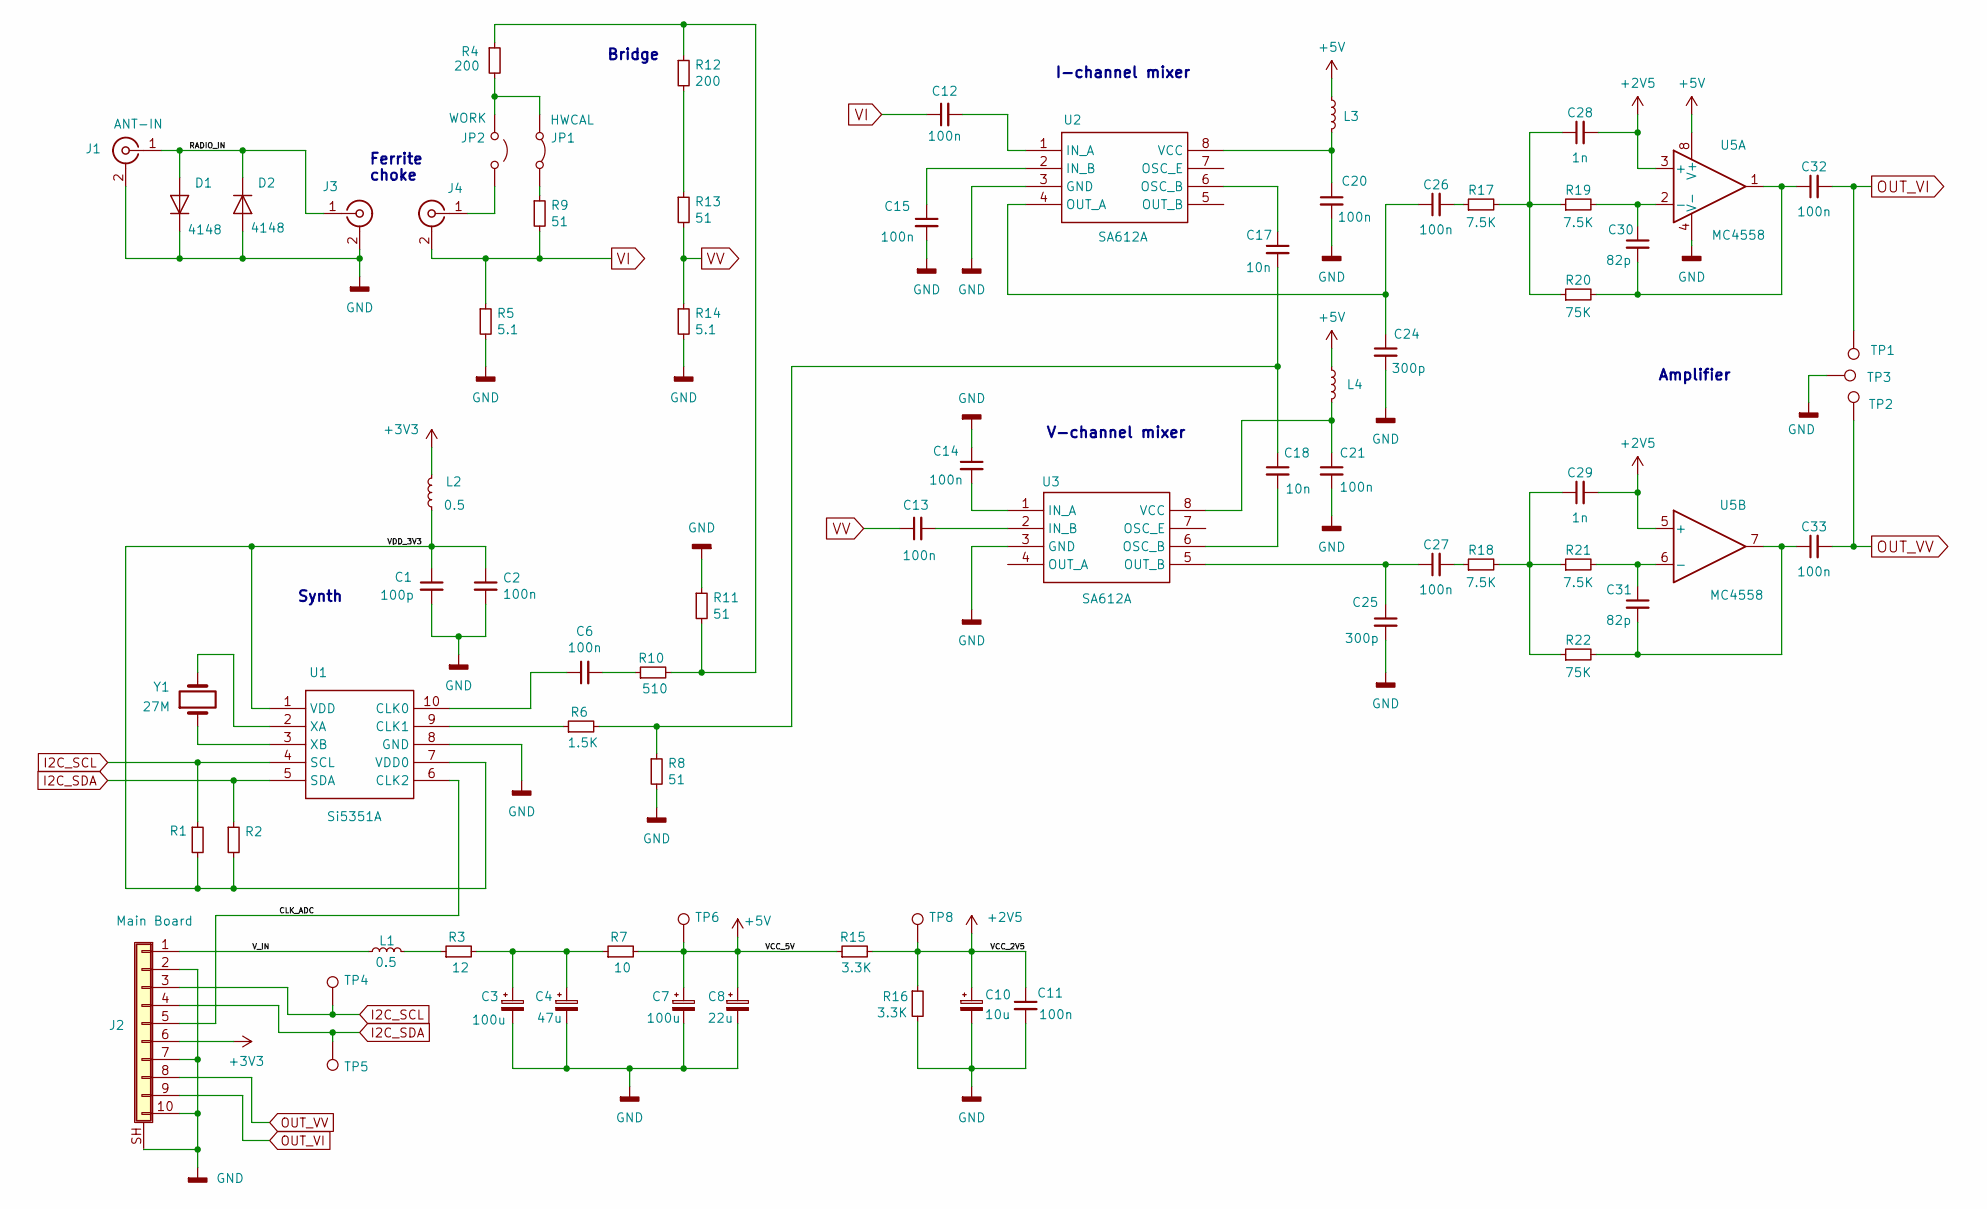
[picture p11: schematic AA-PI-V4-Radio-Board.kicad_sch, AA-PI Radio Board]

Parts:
C1: 100p; C_0805_2012Metric_Pad1.15x1.40mm_HandSolder
C2, C6, C11, C12, C13, C14, C15, C20, C21, C26, C27, C32, C33: 100n; C_0805_2012Metric_Pad1.15x1.40mm_HandSolder
C3, C7: 100u; CP_EIA-7343-31_Kemet-D
C4: 47u; CP_EIA-3528-21_Kemet-B
C8: 22u; CP_EIA-3528-21_Kemet-B
C10: 10u; CP_EIA-3528-21_Kemet-B
C17, C18: 10n; C_0805_2012Metric_Pad1.15x1.40mm_HandSolder
C24, C25: 300p; C_0805_2012Metric_Pad1.15x1.40mm_HandSolder
C28, C29: 1n; C_0805_2012Metric_Pad1.15x1.40mm_HandSolder
C30, C31: 82p; C_0805_2012Metric_Pad1.15x1.40mm_HandSolder
D1, D2: 4148; D_SOD-323_HandSoldering
J1: ANT-IN; SMA_Amphenol_901-144_Vertical
J2: Main Board; 1.25-AB-SMT-10pin-Vertical
J3, J4: INDUCT; MMCX_Molex_73415-1471_Vertical
JP1: HWCAL; PinHeader_1x02_P2.00mm_Vertical
JP2: WORK; PinHeader_1x02_P2.00mm_Vertical
L1, L2, L3, L4: 0.5; L_0805_2012Metric_Pad1.15x1.40mm_HandSolder
R1, R2: 10K; R_0805_2012Metric_Pad1.15x1.40mm_HandSolder
R3: 12; R_0805_2012Metric_Pad1.15x1.40mm_HandSolder
R4, R12: 200; R_0805_2012Metric_Pad1.15x1.40mm_HandSolder
R5, R14: 5.1; R_0805_2012Metric_Pad1.15x1.40mm_HandSolder
R6: 1.5K; R_0805_2012Metric_Pad1.15x1.40mm_HandSolder
R7: 10; R_0805_2012Metric_Pad1.15x1.40mm_HandSolder
R8, R9, R11, R13: 51; R_0805_2012Metric_Pad1.15x1.40mm_HandSolder
R10: 510; R_0805_2012Metric_Pad1.15x1.40mm_HandSolder
R15, R16: 3.3K; R_0805_2012Metric_Pad1.15x1.40mm_HandSolder
R17, R18, R19, R21: 7.5K; R_0805_2012Metric_Pad1.15x1.40mm_HandSolder
R20, R22: 75K; R_0805_2012Metric_Pad1.15x1.40mm_HandSolder
TP1, TP2, TP3, TP4, TP5, TP6, TP8: TestPoint; TestPoint_THTPad_D1.0mm_Drill0.5mm
U1: Si5351A; SOP50P490X110-10N; Manufacturer_Part_Number Si5351A-B-GT
U2, U3: SA612A; SOIC127P600X175-8N; Manufacturer_Part_Number SA612A
U5: MC4558; SOIC127P600X175-8N
Y1: 27M; Crystal_SMD_5032-2Pin_5.0x3.2mm

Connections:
+2V5: C10.1, C11.1, C28.2, C29.2, R15.2, R16.1, TP8.1, U5.3 (+), U5.5 (+)
+3V3: J2.6, L2.1
+5V: C7.1, C8.1, L3.1, L4.1, R7.2, R15.1, TP6.1, U5.8 (V+); also elsewhere on the board
/CLK_ADC: J2.5, U1.6 (CLK2)
/RADIO_IN: D1.2 (A), D2.1 (K), J1.1 (In), J3.1 (In)
/VDD_3V3: C1.1, C2.1, L2.2, R1.2, R2.2, U1.1 (VDD), U1.7 (VDD0)
/V_IN: J2.1, L1.1
GND: C1.2, C2.2, C3.2, C4.2, C7.2, C8.2, C10.2, C11.2, C14.1, C15.2, C20.2, C21.2, C24.2, C25.2, D1.1 (K), D2.2 (A), J1.2 (Ext), J2.2, J2.7, J2.10, J2.SH (Shield), J3.2 (Ext), R5.2, R8.2, R11.1, R14.2, R16.2, TP3.1, U1.8 (GND), U2.3 (GND), U3.3 (GND), U5.4 (V-); also elsewhere on the board
I2C_SCL: J2.3, R1.1, TP4.1, U1.4 (SCL)
I2C_SDA: J2.4, R2.1, TP5.1, U1.5 (SDA)
unnamed 10: C3.1, C4.1, R3.2, R7.1; also elsewhere on the board
unnamed: C6.2, R10.1
unnamed: C17.2, C18.1, R6.2, R8.1
unnamed: C26.2, R17.1
unnamed: C27.2, R18.1
unnamed: C28.1, R17.2, R19.1, R20.1
unnamed: C29.1, R18.2, R21.1, R22.1
unnamed: C30.2, C32.1, R20.2, U5.1
unnamed: C31.2, C33.1, R22.2, U5.7
unnamed: J4.1 (In), JP2.2 (B)
unnamed: JP1.1 (A), JP2.1 (A), R4.2
unnamed: JP1.2 (B), R9.1
unnamed: L1.2, R3.1
unnamed: R4.1, R10.2, R11.2, R12.1
unnamed: R12.2, R13.1
unnamed: C6.1, U1.10 (CLK0)
unnamed: R6.1, U1.9 (CLK1)
unnamed: U1.2 (XA), Y1.2
unnamed: U1.3 (XB), Y1.1
unnamed: C12.2, U2.1 (IN_A)
unnamed: C15.1, U2.2 (IN_B)
unnamed: C17.1, U2.6 (OSC_B)
unnamed: C24.1, C26.1, U2.4 (OUT_A)
unnamed: C20.1, L3.2, U2.8 (VCC)
unnamed: C14.2, U3.1 (IN_A)
unnamed: C13.2, U3.2 (IN_B)
unnamed: C18.2, U3.6 (OSC_B)
unnamed: C25.1, C27.1, U3.5 (OUT_B)
unnamed: C21.1, L4.2, U3.8 (VCC)
unnamed: C30.1, R19.2, U5.2 (-)
unnamed: C31.1, R21.2, U5.6 (-)
OUT_VI: C32.2, J2.9, TP1.1
OUT_VV: C33.2, J2.8, TP2.1
VI: C12.1, J4.2 (Ext), R5.1, R9.2
VV: C13.1, R13.2, R14.1

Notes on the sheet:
Ferrite
choke
V-channel mixer
Amplifier
Synth
I-channel mixer
Bridge

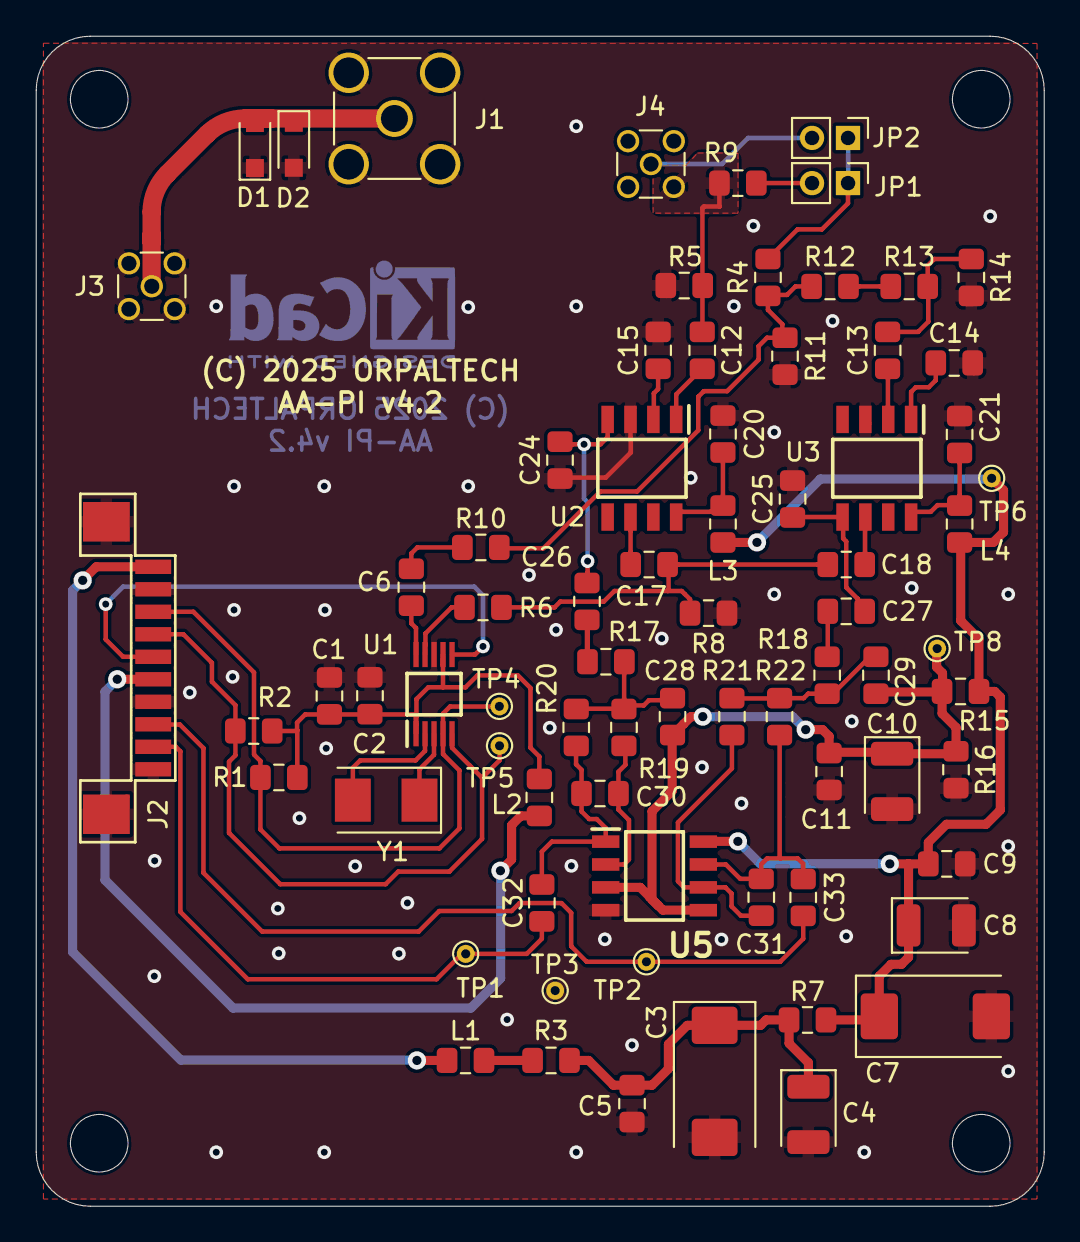
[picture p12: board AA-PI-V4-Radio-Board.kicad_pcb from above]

Board: 2 copper layers, 56.0 x 65.0 mm, 79 parts (0 on the bottom side), 45 nets.

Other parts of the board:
C5, C9: 100n; C_0805_2012Metric_Pad1.15x1.40mm_HandSolder
MH1, MH2, MH3, MH4: MountingHole_3.2mm_M3_DIN965

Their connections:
+5V: C9.1; also elsewhere on the board
GND: C5.2, C9.2; also elsewhere on the board
unnamed 10: C5.1; also elsewhere on the board

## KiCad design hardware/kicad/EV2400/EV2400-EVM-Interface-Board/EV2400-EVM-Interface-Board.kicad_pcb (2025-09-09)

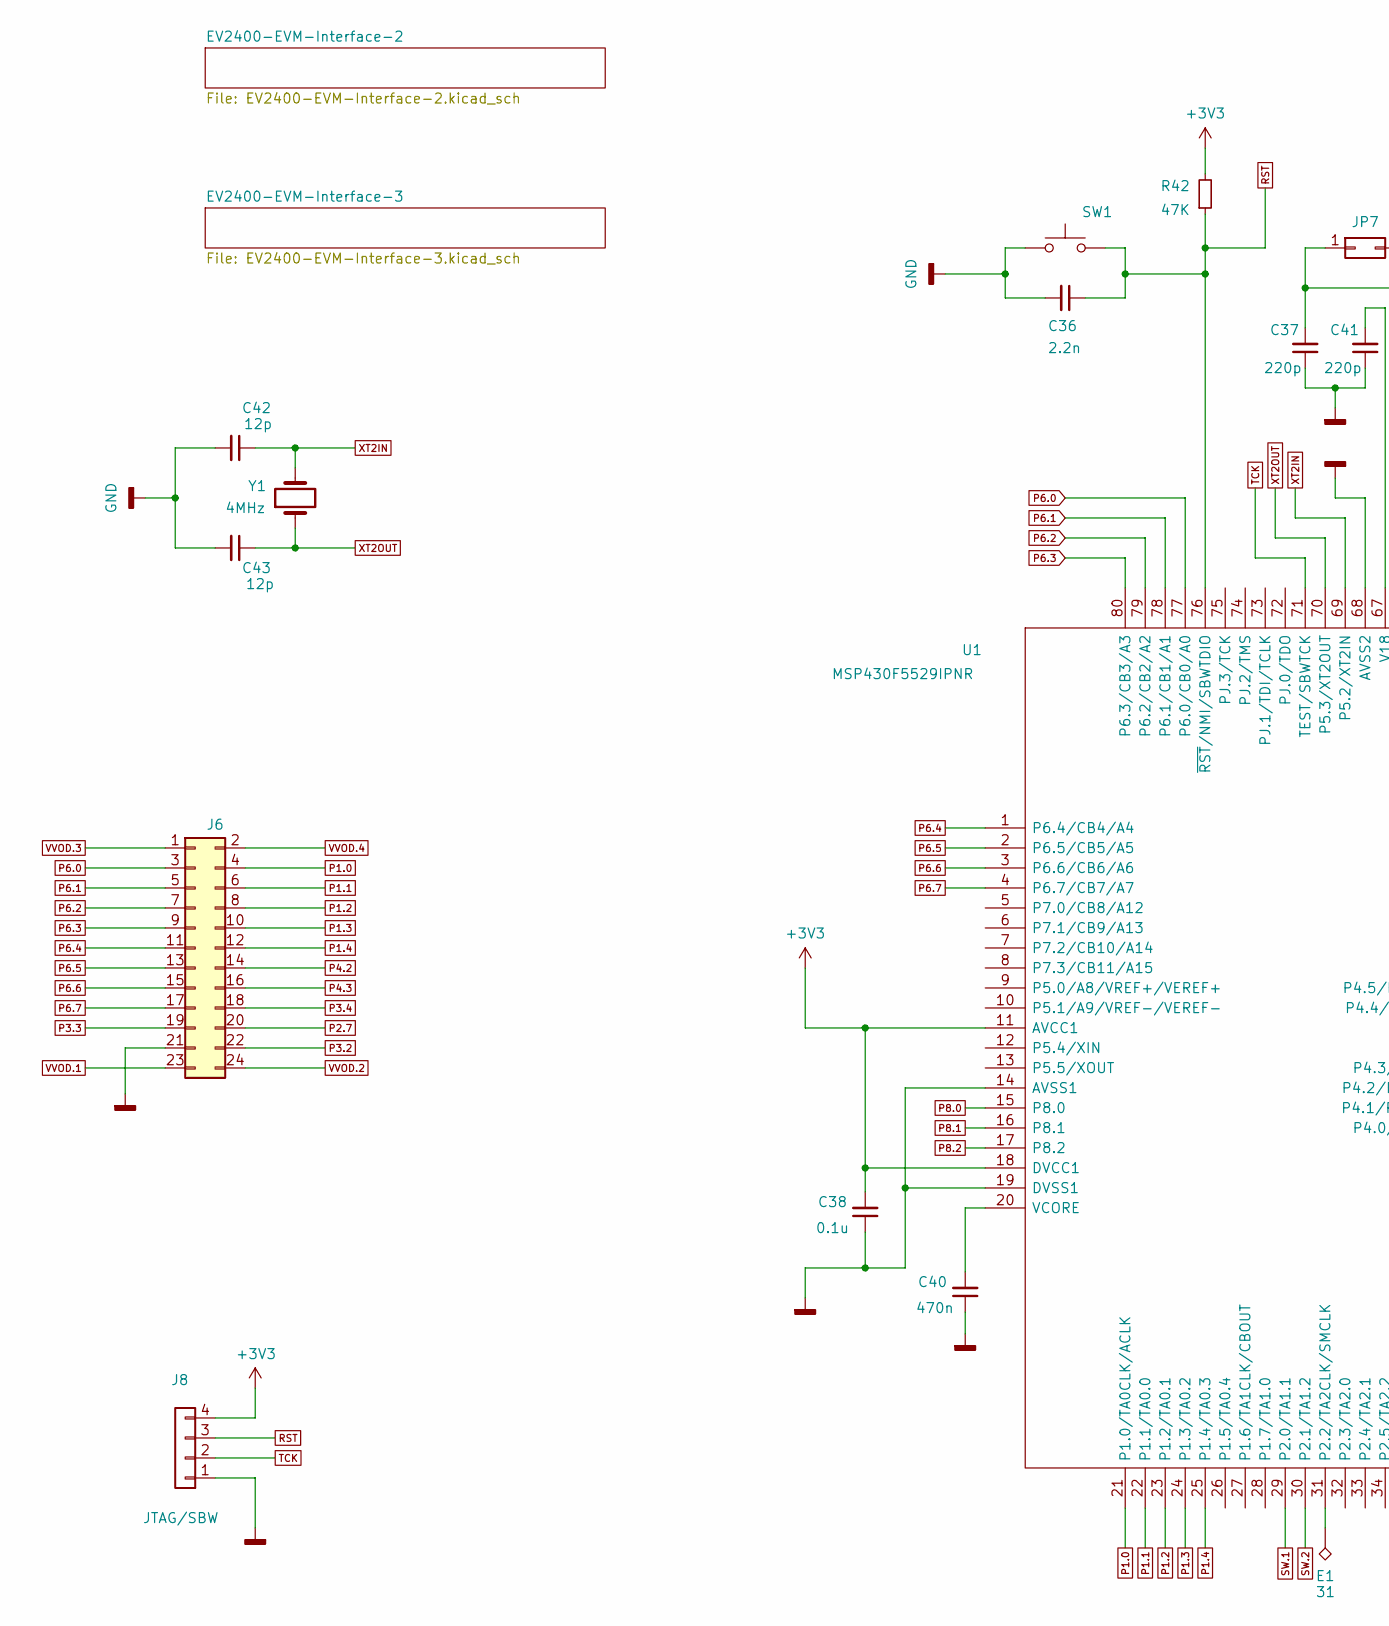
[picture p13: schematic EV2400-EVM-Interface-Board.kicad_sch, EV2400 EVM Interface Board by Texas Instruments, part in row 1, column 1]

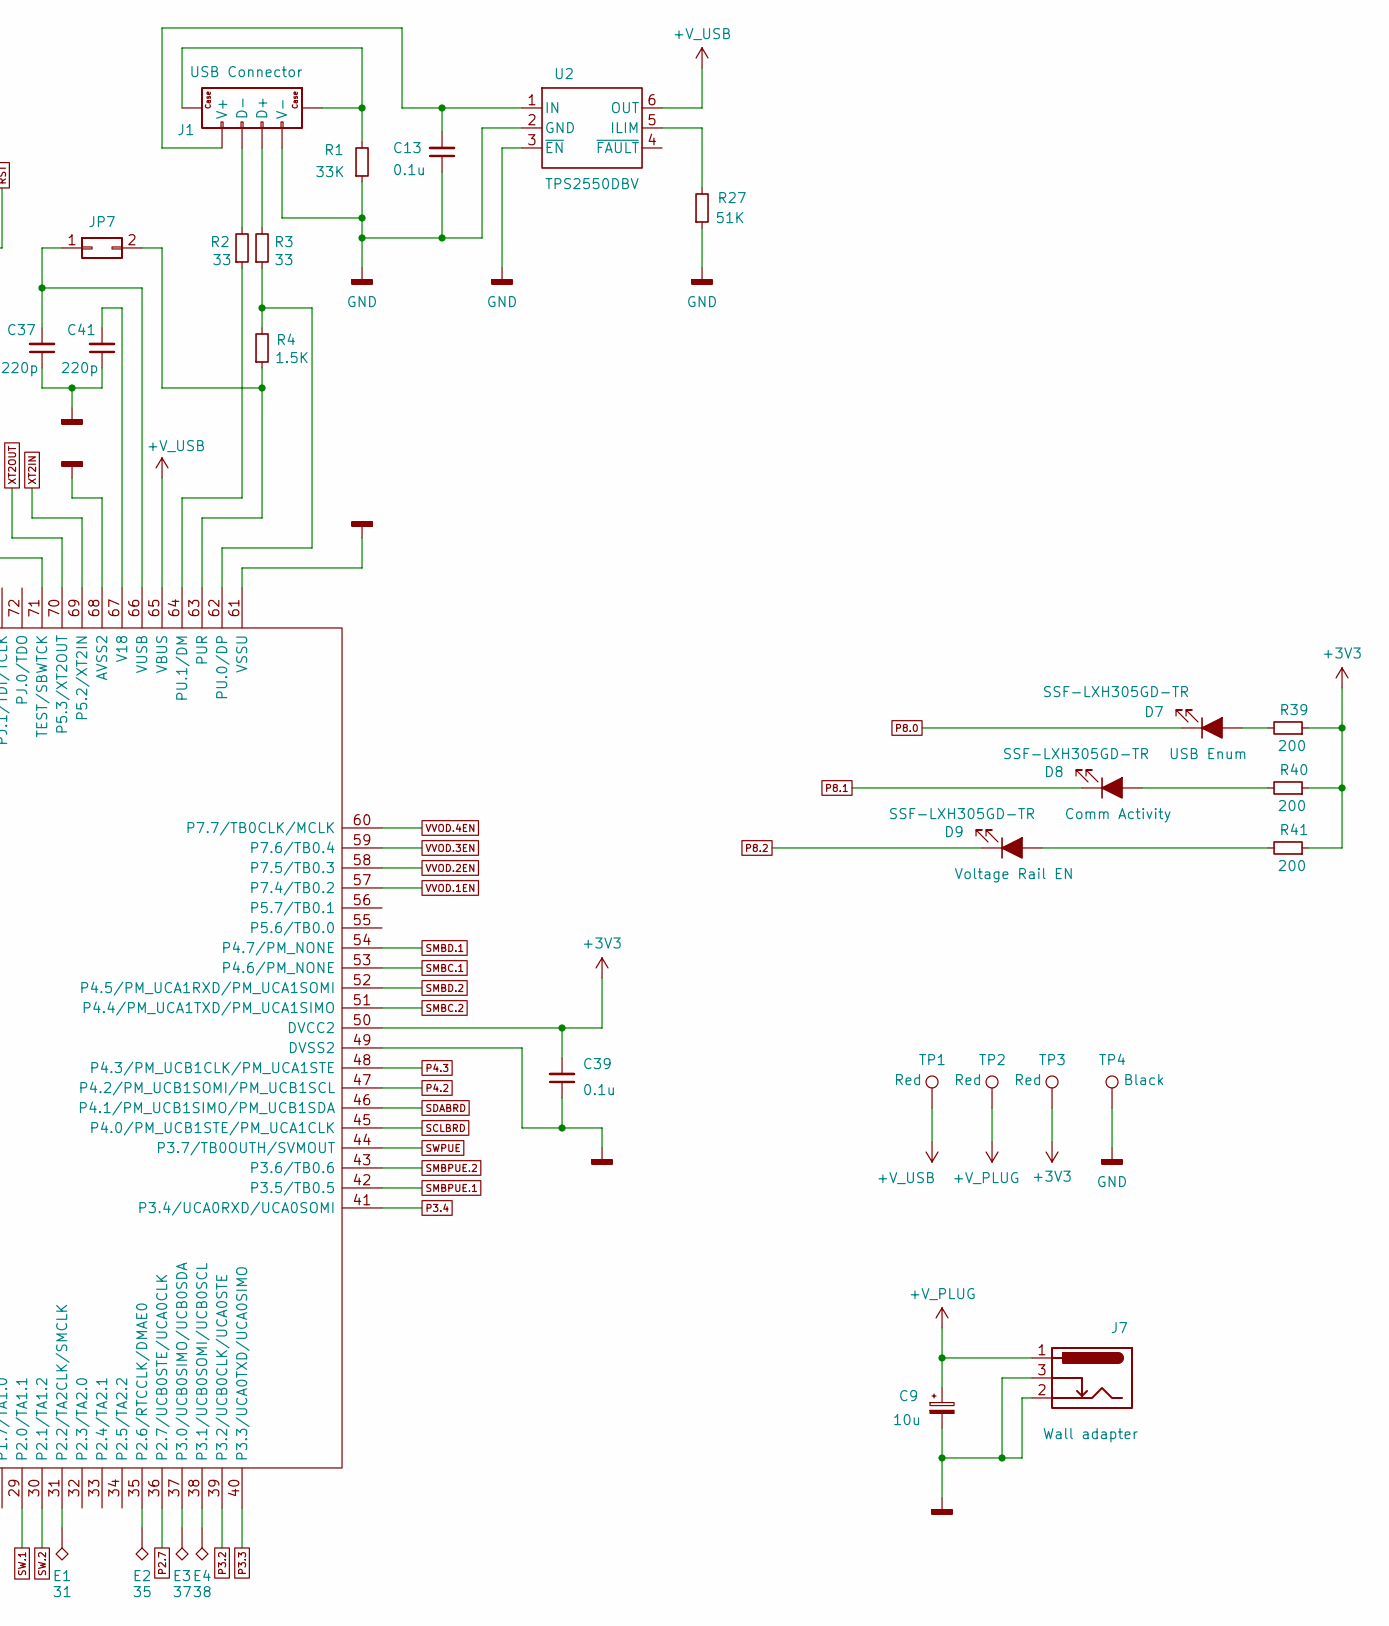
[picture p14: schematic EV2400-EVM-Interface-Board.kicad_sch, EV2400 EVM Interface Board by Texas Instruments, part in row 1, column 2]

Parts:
C9: 10u; CP_EIA-3216-18_Kemet-A
C13, C38, C39: 0.1u; C_0603_1608Metric
C36: 2.2n; C_0603_1608Metric
C37, C41: 220p; C_0603_1608Metric
C40: 470n; C_0603_1608Metric
C42, C43: 12p; C_0603_1608Metric
D7, D8, D9: SSF-LXH305GD-TR; SSFLXH305GDTR
E1: 31; TestPoint_Pad_1.5x1.5mm
E2: 35; TestPoint_Pad_1.5x1.5mm
E3: 37; TestPoint_Pad_1.5x1.5mm
E4: 38; TestPoint_Pad_1.5x1.5mm
J1: USB Connector; USB_B_OST_USB-B1HSxx_Horizontal
J6: Conn_02x12_Odd_Even; PinHeader_2x12_P2.54mm_Horizontal
J7: Wall adapter; DC-050-SMD-Power-Jack
J8: JTAG/SBW; Molex_KK-254_AE-6410-04A_1x04_P2.54mm_Vertical
JP7: Conn_02x01; PinHeader_1x02_P2.54mm_Vertical
R1: 33K; R_0603_1608Metric
R2, R3: 33; R_0603_1608Metric
R4: 1.5K; R_0603_1608Metric
R27: 51K; R_0603_1608Metric
R39, R40, R41: 200; R_0603_1608Metric
R42: 47K; R_0603_1608Metric
SW1: EVQPSD02K
TP1, TP2, TP3, TP4: TestPoint; TestPoint_THTPad_D2.0mm_Drill1.0mm
U1: MSP430F5529IPNR; QFP50P1400X1400X160-80N; Manufacturer_Part_Number MSP430F5529IPNR
U2: TPS2550DBV; SOT95P280X145-6N; Manufacturer_Part_Number TPS2550DBV
Y1: 4MHz; Crystal_SMD_HC49-SD

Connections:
+3V3: C38.2, C39.2, J8.4, R39.1, R40.1, R41.1, R42.2, TP3.1, U1.11 (AVCC1), U1.18 (DVCC1), U1.50 (DVCC2); also elsewhere on the board
+V_PLUG: C9.1, J7.1, TP2.1; also elsewhere on the board
+V_USB: TP1.1, U1.65 (VBUS), U2.6 (OUT); also elsewhere on the board
GND: C9.2, C13.1, C36.2, C37.1, C38.1, C39.1, C40.1, C41.1, C42.2, C43.2, J1.4 (V-), J6.21, J7.2, J7.3, J8.1, R1.1, R27.1, SW1.1, TP4.1, U1.14 (AVSS1), U1.19 (DVSS1), U1.49 (DVSS2), U1.61 (VSSU), U1.68 (AVSS2), U2.2 (GND), U2.3 (~EN); also elsewhere on the board
unnamed: D7.2 (A), R39.2
unnamed: D8.2 (A), R40.2
unnamed: D9.2 (A), R41.2
unnamed: J1.3 (D+), R3.2
unnamed: J1.2 (D-), R2.2
unnamed: J1.5, R1.2
unnamed: C13.2, J1.1 (V+), U2.1 (IN)
unnamed: C37.2, JP7.1, U1.66 (VUSB)
unnamed: JP7.2, R4.1, U1.63 (PUR)
unnamed: E1.1, U1.31 (P2.2/TA2CLK/SMCLK)
unnamed: E2.1, U1.35 (P2.6/RTCCLK/DMAE0)
unnamed: E3.1, U1.37 (P3.0/UCB0SIMO/UCB0SDA)
unnamed: E4.1, U1.38 (P3.1/UCB0SOMI/UCB0SCL)
unnamed: R3.1, R4.2, U1.62 (PU.0/DP)
unnamed: R2.1, U1.64 (PU.1/DM)
unnamed: C41.2, U1.67 (V18)
unnamed: C40.2, U1.20 (VCORE)
unnamed: R27.2, U2.5 (ILIM)
P1.0: J6.4, U1.21 (P1.0/TA0CLK/ACLK)
P1.1: J6.6, U1.22 (P1.1/TA0.0)
P1.2: J6.8, U1.23 (P1.2/TA0.1)
P1.3: J6.10, U1.24 (P1.3/TA0.2)
P1.4: J6.12, U1.25 (P1.4/TA0.3)
P2.7: J6.20, U1.36 (P2.7/UCB0STE/UCA0CLK)
P3.2: J6.22, U1.39 (P3.2/UCB0CLK/UCA0STE)
P3.3: J6.19, U1.40 (P3.3/UCA0TXD/UCA0SIMO)
P3.4: J6.18, U1.41 (P3.4/UCA0RXD/UCA0SOMI)
P4.2: J6.14, U1.47 (P4.2/PM_UCB1SOMI/PM_UCB1SCL)
P4.3: J6.16, U1.48 (P4.3/PM_UCB1CLK/PM_UCA1STE)
P6.0: J6.3, U1.77 (P6.0/CB0/A0)
P6.1: J6.5, U1.78 (P6.1/CB1/A1)
P6.2: J6.7, U1.79 (P6.2/CB2/A2)
P6.3: J6.9, U1.80 (P6.3/CB3/A3)
P6.4: J6.11, U1.1 (P6.4/CB4/A4)
P6.5: J6.13, U1.2 (P6.5/CB5/A5)
P6.6: J6.15, U1.3 (P6.6/CB6/A6)
P6.7: J6.17, U1.4 (P6.7/CB7/A7)
P8.0: D7.1 (K), U1.15 (P8.0)
P8.1: D8.1 (K), U1.16 (P8.1)
P8.2: D9.1 (K), U1.17 (P8.2)
RST: C36.1, J8.3, R42.1, SW1.2, U1.76 (~RST/NMI/SBWTDIO)
SCLBRD: U1.45 (P4.0/PM_UCB1STE/PM_UCA1CLK); also elsewhere on the board
SDABRD: U1.46 (P4.1/PM_UCB1SIMO/PM_UCB1SDA); also elsewhere on the board
SMBC.1: U1.53 (P4.6/PM_NONE); also elsewhere on the board
SMBC.2: U1.51 (P4.4/PM_UCA1TXD/PM_UCA1SIMO); also elsewhere on the board
SMBD.1: U1.54 (P4.7/PM_NONE); also elsewhere on the board
SMBD.2: U1.52 (P4.5/PM_UCA1RXD/PM_UCA1SOMI); also elsewhere on the board
SMBPUE.1: U1.42 (P3.5/TB0.5); also elsewhere on the board
SMBPUE.2: U1.43 (P3.6/TB0.6); also elsewhere on the board
SW.1: U1.29 (P2.0/TA1.1); also elsewhere on the board
SW.2: U1.30 (P2.1/TA1.2); also elsewhere on the board
SWPUE: U1.44 (P3.7/TB0OUTH/SVMOUT); also elsewhere on the board
TCK: J8.2, U1.71 (TEST/SBWTCK)
VVOD.1: J6.23; also elsewhere on the board
VVOD.1EN: U1.57 (P7.4/TB0.2); also elsewhere on the board
VVOD.2: J6.24; also elsewhere on the board
VVOD.2EN: U1.58 (P7.5/TB0.3); also elsewhere on the board
VVOD.3: J6.1; also elsewhere on the board
VVOD.3EN: U1.59 (P7.6/TB0.4); also elsewhere on the board
VVOD.4: J6.2; also elsewhere on the board
VVOD.4EN: U1.60 (P7.7/TB0CLK/MCLK); also elsewhere on the board
XT2IN: C42.1, U1.69 (P5.2/XT2IN), Y1.2
XT2OUT: C43.1, U1.70 (P5.3/XT2OUT), Y1.1


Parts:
C1, C2, C3, C4, C5, C6, C7, C11, C15, C16: 0.1u; C_0603_1608Metric
C8, C10: 2.2u; C_0805_2012Metric
C12: 4.7u; C_0805_2012Metric
C14, C17: 10u; CP_EIA-3216-18_Kemet-A
D1, D2, D3, D4, D5, D6: SL05T1G; SOT96P237X111-3N; Manufacturer_Part_Number SL05T1G
J2, J3, J4, J5: Conn_01x04; Molex_22053041
JP1, JP2, JP3, JP4, JP5, JP6: Conn_02x01; PinHeader_1x02_P2.54mm_Vertical
Q1, Q2, Q3, Q4, Q5, Q6: BSS209PW; SOT65P210X100-3N
Q7, Q8, Q9: 2N7002W; SOT65P220X100-3N
R5, R6, R7, R12, R15, R16, R19, R20, R25, R43, R44, R45: 10K; R_0603_1608Metric
R8, R9, R17, R18, R21, R23: 100; R_0603_1608Metric
R10, R11, R13, R14, R22, R24: 20K; R_0603_1608Metric
R26: 470; R_0603_1608Metric
R28, R46, R47, R48: 100K; R_0603_1608Metric
U3: TPS76333DBV; SOT95P280X145-5N; Manufacturer_Part_Number TPS76333DBVT
U4, U5, U6: ST2329BQTR; QFN40P120X140X55-8N; Manufacturer_Part_Number ST2329BQTR
U7: TPS79650DCQ; SOT127P706X180-6N; Manufacturer_Part_Number TPS79650DCQ
U8: TPS2113APWR; SOP65P640X120-8N; Manufacturer_Part_Number TPS2113APWR

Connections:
5V-MUX: C14.1, C15.1, R5.2, R16.2, R19.2, R28.1, R45.1, U3.1 (IN), U8.7 (OUT); also elsewhere on the board
+3V3: C1.1, C4.1, C5.1, C17.1, R6.1, R7.1, R12.1, R15.1, R20.1, R25.1, U3.5 (OUT), U4.1 (VL), U5.1 (VL), U6.1 (VL); also elsewhere on the board
+V_PLUG: C7.1, U7.1 (EN), U7.2 (VIN); also elsewhere on the board
+V_USB: C12.1, U8.6 (IN2); also elsewhere on the board
GND: C1.2, C2.2, C3.2, C4.2, C5.2, C6.2, C7.2, C8.2, C10.2, C11.2, C12.2, C14.2, C15.2, C16.2, C17.2, D1.2, D2.2, D3.2, D4.2, D5.2, D6.2, J2.1, J3.1, J4.1, J5.1, Q7.2 (S), Q8.2 (S), Q9.2 (S), R26.2, R44.2, U3.2 (GND), U4.4 (GND), U5.4 (GND), U6.4 (GND), U7.3 (GND), U7.6 (GND), U8.2 (~EN), U8.5 (GND); also elsewhere on the board
unnamed: D2.1, J2.2, R8.2, R10.2
unnamed: D1.1, J2.3, R9.2, R11.2
unnamed: D4.1, J3.2, R13.2, R17.2
unnamed: D3.1, J3.3, R14.2, R18.2
unnamed: D5.1, J4.3, R21.2, R22.2
unnamed: D6.1, J5.3, R23.2, R24.2
unnamed: JP1.2, R8.1, U4.7 (IO_VCC1)
unnamed: JP2.2, R9.1, U4.6 (IO_VCC2)
unnamed: JP3.2, R17.1, U5.7 (IO_VCC1)
unnamed: JP4.2, R18.1, U5.6 (IO_VCC2)
unnamed: JP5.2, R23.1, U6.6 (IO_VCC2)
unnamed: JP6.2, R21.1, U6.7 (IO_VCC1)
unnamed: Q1.3 (D), R10.1
unnamed: Q1.1 (G), Q2.1 (G), Q7.3 (D), R46.2
unnamed: Q2.3 (D), R11.1
unnamed: Q3.3 (D), R13.1
unnamed: Q3.1 (G), Q4.1 (G), Q8.3 (D), R47.2
unnamed: Q4.3 (D), R14.1
unnamed: Q5.3 (D), R22.1
unnamed: Q5.1 (G), Q6.1 (G), Q9.3 (D), R48.2
unnamed: Q6.3 (D), R24.1
unnamed: C16.1, R28.2, U3.3 (EN)
unnamed: R5.1, U4.5 (OE)
unnamed: R16.1, U5.5 (OE)
unnamed: R19.1, U6.5 (OE)
unnamed: C10.1, U7.5 (NR/FB)
unnamed: C8.1, C11.1, R43.1, U7.4 (VOUT), U8.8 (IN1)
unnamed: R26.1, U8.4 (ILIM)
unnamed: R45.2, U8.1 (STAT)
unnamed: R43.2, R44.1, U8.3 (VSNS)
SMBC.1: JP1.1, R7.2, U4.2 (IO_VL1); also elsewhere on the board
SMBC.2: JP3.1, R12.2, U5.2 (IO_VL1); also elsewhere on the board
SMBD.1: JP2.1, R6.2, U4.3 (IO_VL2); also elsewhere on the board
SMBD.2: JP4.1, R15.2, U5.3 (IO_VL2); also elsewhere on the board
SMBPUE.1: Q7.1 (G); also elsewhere on the board
SMBPUE.2: Q8.1 (G); also elsewhere on the board
SW.1: JP6.1, R20.2, U6.2 (IO_VL1); also elsewhere on the board
SW.2: JP5.1, R25.2, U6.3 (IO_VL2); also elsewhere on the board
SWPUE: Q9.1 (G); also elsewhere on the board
VPUV.1: C2.1, C6.1, Q1.2 (S), Q2.2 (S), Q5.2 (S), Q6.2 (S), R46.1, R48.1, U4.8 (VCC), U6.8 (VCC); also elsewhere on the board
VPUV.2: C3.1, Q3.2 (S), Q4.2 (S), R47.1, U5.8 (VCC); also elsewhere on the board
VVOD.1: J2.4; also elsewhere on the board
VVOD.2: J3.4; also elsewhere on the board
VVOD.3: J4.2, J5.2; also elsewhere on the board
VVOD.4: J4.4, J5.4; also elsewhere on the board

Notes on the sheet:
VVOD.4
VSS
SW2
SMBC.1 / SCL.1
VVOD.3
VVOD.1
SMBC.2 / SCL.2
SMBD.2 / SDA.2
VVOD.2
SMBD.1 / SDA.1
SW1


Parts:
C18, C19, C20, C21, C22, C23, C24, C25, C26, C27, C28, C29, C30, C31, C32, C33, C34, C35: 0.1u; C_0603_1608Metric
R29, R30, R31, R32, R33, R34, R35, R36, R37, R38: 10K; R_0603_1608Metric
U9, U14: ISL90842UIV1427Z; SOP65P640X105-14N; Manufacturer_Part_Number ISL90842UIV1427Z
U10, U11, U12, U13, U15, U18: TPS73601DBV; SOT95P280X145-5N; Manufacturer_Part_Number TPS73601DBV

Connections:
5V-MUX: C18.1, C21.1, C24.1, C27.1, C30.1, C35.1, U9.12 (VCC), U10.1 (VIN), U11.1 (VIN), U12.1 (VIN), U13.1 (VIN), U14.11 (A1), U14.12 (VCC), U15.1 (VIN), U15.3 (EN), U18.1 (VIN), U18.3 (EN); also elsewhere on the board
+3V3: R31.2, R32.2, R35.2, R36.2; also elsewhere on the board
GND: C18.2, C20.2, C21.2, C23.2, C24.2, C26.2, C27.2, C29.2, C30.2, C32.2, C33.2, C35.2, R29.2, R30.2, R33.2, R34.2, R37.2, R38.2, U9.5 (GND), U9.10 (A0), U9.11 (A1), U10.2 (GND), U11.2 (GND), U12.2 (GND), U13.2 (GND), U14.5 (GND), U14.10 (A0), U15.2 (GND), U18.2 (GND); also elsewhere on the board
unnamed: C19.2, R29.1, U9.1 (RH3), U10.4 (NR/FB)
unnamed: C22.2, R30.1, U9.13 (RH0), U11.4 (NR/FB)
unnamed: C25.2, R33.1, U9.7 (RH2), U12.4 (NR/FB)
unnamed: C28.2, R34.1, U9.9 (RH1), U13.4 (NR/FB)
unnamed: C34.2, R37.1, U14.13 (RH0), U15.4 (NR/FB)
unnamed: C31.2, R38.1, U14.7 (RH2), U18.4 (NR/FB)
SCLBRD: R31.1, R35.1, U9.3 (SCL), U14.3 (SCL); also elsewhere on the board
SDABRD: R32.1, R36.1, U9.4 (SDA), U14.4 (SDA); also elsewhere on the board
VPUV.1: C33.1, C34.1, U14.14 (RW0), U15.5 (OUT); also elsewhere on the board
VPUV.2: C31.1, C32.1, U14.6 (RW2), U18.5 (OUT); also elsewhere on the board
VVOD.1: C19.1, C20.1, U9.2 (RW3), U10.5 (OUT); also elsewhere on the board
VVOD.1EN: U10.3 (EN); also elsewhere on the board
VVOD.2: C25.1, C26.1, U9.6 (RW2), U12.5 (OUT); also elsewhere on the board
VVOD.2EN: U12.3 (EN); also elsewhere on the board
VVOD.3: C22.1, C23.1, U9.14 (RW0), U11.5 (OUT); also elsewhere on the board
VVOD.3EN: U11.3 (EN); also elsewhere on the board
VVOD.4: C28.1, C29.1, U9.8 (RW1), U13.5 (OUT); also elsewhere on the board
VVOD.4EN: U13.3 (EN); also elsewhere on the board

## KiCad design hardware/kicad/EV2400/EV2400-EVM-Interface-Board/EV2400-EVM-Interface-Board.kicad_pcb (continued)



Board: 2 copper layers, 102.1 x 68.8 mm, 150 parts (68 on the bottom side), 106 nets.

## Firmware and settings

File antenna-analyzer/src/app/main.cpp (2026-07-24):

/*
 * This file is part of the ORPALTECH AA-PI project
 *  (https://github.com/orpaltech/aapi).
 *
 * Copyright (c) 2013-2026 ORPAL Technology, Inc.
 *
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
 * You should have received a copy of the GNU General Public License
 * along with this program. If not, see <http://www.gnu.org/licenses/>.
 */

#include <QFile>
#include <QGuiApplication>
#include <QProcess>
#include <QQmlApplicationEngine>
#include <QQmlContext>
#include <QQuickWindow>
#include <QApplication>
#include "aapi_application.h"
#include "ui/aapi_aquish_style.h"
#include "ui/aapi_messages.h"


#define AAPI_QML_NAMESPACE  "ru.orpaltech.aapi"
#define AAPI_QML_VER_MAJOR  AAPI_VERSION_MAJOR
#define AAPI_QML_VER_MINOR  AAPI_VERSION_MINOR
#define AAPI_QML_VER    AAPI_QML_VER_MAJOR,AAPI_QML_VER_MINOR

// Define your log file path
static QString logFilePath = QString("/var/log/aapi_%1.log").arg(QDateTime::currentDateTime().toString("ddMMyyyy-hhmmss"));

void logFileMessage(QtMsgType type, const QMessageLogContext &context, const QString &msg)
{
    QFile file(logFilePath);
    if (file.open(QIODevice::Append | QIODevice::Text)) {

        QTextStream out(&file);
        out << QDateTime::currentDateTime().toString("yyyy-MM-dd hh:mm:ss.zzz ");

        switch (type) {
        case QtDebugMsg:
            out << "[DEBUG] ";
            break;
        case QtInfoMsg:
            out << "[INFO] ";
            break;
        case QtWarningMsg:
            out << "[WARNING] ";
            break;
        case QtCriticalMsg:
            out << "[CRITICAL] ";
            break;
        case QtFatalMsg:
            out << "[FATAL] ";
            break;
        }

        out << msg << " (" << context.file << ":" << context.line << ", " << context.function << ")\n";
        file.close();
    }
}


int main(int argc, char *argv[])
{
    qputenv("QT_IM_MODULE", QByteArray("qtvirtualkeyboard"));
    qputenv("QT_MESSAGE_PATTERN", QByteArray("[%{time process} %{type}] %{appname} %{category} %{function} - %{message}"));

    qInstallMessageHandler(logFileMessage);

    QSurfaceFormat format = QSurfaceFormat::defaultFormat();
    format.setSamples(0);
    QSurfaceFormat::setDefaultFormat(format);

    QAAPiShutdownManager shutdownManager;
    int ret = shutdownManager.openDevice();
    if (AAPI_FAILED( ret )) {
        return ret;
    }

    do
    {
        QApplication app( argc, argv );
        app.setApplicationName("AA-Pi");
        app.setApplicationDisplayName("Antenna Analyzer Pi");
        app.setApplicationVersion(STRINGIFY(AAPI_VERSION));
        app.setOrganizationName("ORPAL Technology, Inc");

        QAAPiBaseStyle  *style = new QAAPiAquishStyle( &app );
        QAAPiMessages   *mgs = new QAAPiMessages( &app );
        QAAPiApplication *aapi = new QAAPiApplication( style, mgs, &shutdownManager, &app );

        QScreen *screen = QApplication::primaryScreen();

        qmlRegisterUncreatableType<QAAPiStatusBackend>      (AAPI_QML_NAMESPACE, AAPI_QML_VER, "ApplicationStatusBackend",  AAPI_QML_UNCREATABLE_REASON);
        qmlRegisterUncreatableType<QAAPiViewBackend>        (AAPI_QML_NAMESPACE, AAPI_QML_VER, "ViewBackend",               AAPI_QML_UNCREATABLE_REASON);
        qmlRegisterUncreatableType<QAAPiAboutAppView>       (AAPI_QML_NAMESPACE, AAPI_QML_VER, "AboutAppViewBackend",       AAPI_QML_UNCREATABLE_REASON);
        qmlRegisterUncreatableType<QAAPiConfigurationView>  (AAPI_QML_NAMESPACE, AAPI_QML_VER, "ConfigurationViewBackend",  AAPI_QML_UNCREATABLE_REASON);
        qmlRegisterUncreatableType<QAAPiHWCalibrationView>  (AAPI_QML_NAMESPACE, AAPI_QML_VER, "HWCalibrationViewBackend",  AAPI_QML_UNCREATABLE_REASON);
        qmlRegisterUncreatableType<QAAPiOSLCalibrationView> (AAPI_QML_NAMESPACE, AAPI_QML_VER, "OSLCalibrationViewBackend", AAPI_QML_UNCREATABLE_REASON);
        qmlRegisterUncreatableType<QAAPiMeasurementView>    (AAPI_QML_NAMESPACE, AAPI_QML_VER, "MeasurementViewBackend",    AAPI_QML_UNCREATABLE_REASON);
        qmlRegisterUncreatableType<QAAPiPanoramicScanView>  (AAPI_QML_NAMESPACE, AAPI_QML_VER, "PanoramicScanViewBackend",  AAPI_QML_UNCREATABLE_REASON);
        qmlRegisterUncreatableType<QAAPiSignalProcessView>  (AAPI_QML_NAMESPACE, AAPI_QML_VER, "SignalProcessViewBackend",  AAPI_QML_UNCREATABLE_REASON);
        qmlRegisterUncreatableType<QAAPiGeneratorView>      (AAPI_QML_NAMESPACE, AAPI_QML_VER, "GeneratorViewBackend",      AAPI_QML_UNCREATABLE_REASON);


        do {
            // Set analyzer object as a context property
            QQmlApplicationEngine engine;
            engine.rootContext()->setContextProperty( "aapi", aapi );

            QObject::connect(&engine,
                            &QQmlApplicationEngine::objectCreationFailed,
                            &app,
                            []() { QCoreApplication::exit(-1); },
                            Qt::QueuedConnection);

#ifdef AAPI_DESIGN_MODE
            engine.rootContext()->setContextProperty( "AAPI_DESIGN_MODE", true );
#else
            engine.rootContext()->setContextProperty( "AAPI_DESIGN_MODE", false );
#endif

            ret = aapi->load( );
            if (AAPI_FAILED( ret )) {
                ret = EXIT_FAILURE;
                break;
            }

            engine.loadFromModule("aapi", "Main");
            if (engine.rootObjects().isEmpty()) {
                ret = EXIT_FAILURE;
                break;
            }

            // Get the first root object, assuming it's main window
            QObject *root = engine.rootObjects().first();

            // Cast to QQuickWindow if it's a window type
            aapi->setMainWindow(qobject_cast<QQuickWindow*>(root));

            // Enter application main loop
            ret = app.exec();

        } while(false);

    } while (ret == EXIT_REBOOT); // Check if reboot requested

    // At this point:
    // - app.exec() has returned
    // - All Qt objects cleaned up

    // Check if shutdown was requested and perform system shutdown
    if (shutdownManager.isShutdownRequested()) {

        qInfo() << "Shutdown was requested, proceeding with system poweroff";
        shutdownManager.performSystemShutdown();

        // Should not reach here if poweroff succeeded
        qCritical() << "System poweroff failed or not executed";

    } else {
        qInfo() << "No shutdown requested, normal exit";
    }

    qInfo() << "========================================";
    qInfo() << "Application exiting normally";
    qInfo() << "========================================";

    return ret;
}

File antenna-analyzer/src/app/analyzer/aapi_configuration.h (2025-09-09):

/*
 * This file is part of the ORPALTECH AA-PI project
 *  (https://github.com/orpaltech/aapi).
 *
 * Copyright (c) 2013-2025 ORPAL Technology, Inc.
 *
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
 * You should have received a copy of the GNU General Public License
 * along with this program. If not, see <http://www.gnu.org/licenses/>.
 */

#ifndef AAPI_CONFIGURATION_H
#define AAPI_CONFIGURATION_H

#include <QVariant>
#include <QMutex>
#include <QMutexLocker>
#include "aapi_error.h"
#include "aapi_object.h"
#include "utils/simple_array.h"
#include "utils/simple_variant.h"

///////////////////////////////////////////////////////////////////////////////
// Configuration definitions
///////////////////////////////////////////////////////////////////////////////


#define AAPI_SYSFS_PATH         "/sys/class/vna/aapi0"
#define AAPI_SYSFS_ENABLE       "enable"
#define AAPI_SYSFS_MEASURE_FREQ "measure_freq"
#define AAPI_SYSFS_INT_FREQ     "intermediate_freq"

/* The selected intermediate frequency */
#define AAPI_INT_FREQ_HZ    12281U

/*
 * Frequency range of the analyzer
 */
#define AAPI_BAND_FMIN      500000UL    //BAND_FMIN must be multiple 100000
#define AAPI_BAND_FMAX      158000000UL //BAND_FMAX must be multiple of 100000

#if (AAPI_BAND_FMAX % 100000) != 0 || AAPI_BAND_FMAX <= AAPI_BAND_FMIN || (AAPI_BAND_FMIN % 100000) != 0
    #error "Incorrect band limit settings"
#endif

#define AAPI_IS_FREQ_INBAND(f)      ((f) >= AAPI_BAND_FMIN && (f) <= AAPI_BAND_FMAX)

/* Maximum number of measurements */
#define AAPI_MEASURE_MAX_SCANS      20U

#define AAPI_MAG_CORR_FACTOR        1.  // TODO

///////////////////////////////////////////////////////////////////////////////
// Parameter accessor method declarations
///////////////////////////////////////////////////////////////////////////////

#define AAPI_PARAM_UINT32_ACCESSOR_R(_id, _name)    \
    uint32_t get_ ## _name () const {               \
        return get_value( _id ).toUInt();           \
}

#define AAPI_PARAM_UINT32_ACCESSOR_W(_id, _name)    \
    void set_ ## _name (uint32_t value) {           \
        set_value( _id, value );                    \
    }

#define AAPI_PARAM_INT32_ACCESSOR(_id, _name)   \
    void set_ ## _name (int32_t value) {        \
        set_value( _id, value );                \
    }                                           \
    int32_t get_ ## _name () const {            \
        return get_value( _id ).toInt();        \
	}

#define AAPI_PARAM_UINT32_ACCESSOR(_id, _name)  \
    AAPI_PARAM_UINT32_ACCESSOR_R(_id, _name)    \
    AAPI_PARAM_UINT32_ACCESSOR_W(_id, _name)

#define AAPI_PARAM_UINT8_ACCESSOR(_id, _name)   \
    void set_ ## _name (uint8_t value) {        \
        set_value( _id,                         \
            static_cast<uint32_t> (value));     \
    }                                           \
    uint8_t get_ ## _name () const {            \
        return get_value( _id ).toByte();       \
	}

#define AAPI_PARAM_FLOAT_ACCESSOR(_id, _name)   \
    void set_ ## _name (float value) {      \
        set_value( _id, value );            \
    }                                       \
    float get_ ## _name () const {          \
        return get_value( _id ).toFloat();  \
	}

#define AAPI_PARAM_STRING_ACCESSOR(_id, _name)  \
    void set_ ## _name (const char* value) {    \
        set_value( _id, value );                \
    }                                           \
    AAPiString get_ ## _name () const {         \
        return get_value( _id ).toString();     \
	}

namespace aapi
{

typedef QRecursiveMutex                 AAPiMutex;
typedef QMutexLocker<QRecursiveMutex>   AAPiMutexLocker;

///////////////////////////////////////////////////////////////////////////////
// Enum definitions
///////////////////////////////////////////////////////////////////////////////
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

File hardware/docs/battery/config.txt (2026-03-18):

ProcessingType = 2
NumCellSeries = 1
ElapsedTimeColumn = 2
VoltageColumn = 3
CurrentColumn = 4
TemperatureColumn = 5

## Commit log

2018-10-13 add hardware
    [AA-PI-Display-Board-RaspberryPi3.dsn, AA-PI-Display-Board-RaspberryPi3.kicad_pcb, AA-PI-Display-Board-RaspberryPi3.sch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]
2018-11-03 kicad projects update
    [AA-PI-Display-Board-RaspberryPi3-B.Cu.gbl, AA-PI-Display-Board-RaspberryPi3-B.Mask.gbs, AA-PI-Display-Board-RaspberryPi3-B.SilkS.gbo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]
2018-11-03 rename folder
    [AA-PI-Display-Board-RaspberryPi3.dsn, AA-PI-Display-Board-RaspberryPi3.kicad_pcb, AA-PI-Display-Board-RaspberryPi3.sch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]
2018-11-04 Rotated DSI connector to match RPI orientation
    [AA-PI-Display-Board-RaspberryPi3-B.Cu.gbl, AA-PI-Display-Board-RaspberryPi3-B.Fab.gbr, AA-PI-Display-Board-RaspberryPi3-B.Mask.gbs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]
2018-11-04 Encreased thickness of the antenna route
    [AA-PI-Radio-Board-B.Cu.gbr, AA-PI-Radio-Board-B.Fab.gbr, AA-PI-Radio-Board-B.Mask.gbr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]
2018-11-30 planned update (hardware)
    [AA-PI-Display-Board-RaspberryPi3.kicad_pcb, AA-PI-Display-Board-RaspberryPi3.sch, AA-PI-Radio-Board.kicad_pcb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]
2018-12-05 Display board for NanoPiA64
    [AA-PI-Display-Board-NanoPiA64-B.Cu.gbl, AA-PI-Display-Board-NanoPiA64-B.Mask.gbs, AA-PI-Display-Board-NanoPiA64-B.SilkS.gbo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]
2019-02-23 hardware: kicad schematics
    [AA-PI-Display-Board-NanoPiA64-B.Cu.gbl, AA-PI-Display-Board-NanoPiA64-B.Mask.gbs, AA-PI-Display-Board-NanoPiA64-B.SilkS.gbo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]
2019-03-04 pdf schematic for NanoPi A64 v2.2
2019-08-19 Planned update
    [AA-PI-V3_1-Display-Board-NanoPiA64-LCD-CTP.sch, AA-PI-V3_1-Display-Board-NanoPiA64-VNA-Codec.sch, AA-PI-V3_1-Display-Board-NanoPiA64.dsn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]
2019-08-19 Removed obsolete schematics
    [AA-PI-V2_1-Display-Board-RaspberryPi3.dsn, AA-PI-V2_1-Display-Board-RaspberryPi3.kicad_pcb, AA-PI-V2_1-Display-Board-RaspberryPi3.sch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]
2019-08-19 Add radio board
    [AA-PI-V3_0-Radio-Board.dsn, AA-PI-V3_0-Radio-Board.kicad_pcb, AA-PI-V3_0-Radio-Board.sch]
2019-09-27 Add EV2400 interface
    [AA-PI-V3_0-Radio-Board.dsn, AA-PI-V3_0-Radio-Board.kicad_pcb, AA-PI-V3_0-Radio-Board.sch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]
2019-09-27 removed old AA-PI kicad sources
    [AA-PI-V3_0-Radio-Board.dsn, AA-PI-V3_0-Radio-Board.kicad_pcb, AA-PI-V3_0-Radio-Board.sch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]
2019-10-01 EV2400 PCB update
    [EV2400-EVM-Interface-2.sch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]
2019-11-16 Updates: EV2400 kicad sources
    [EV2400-EVM-Interface-Board-B_Cu.gbr, EV2400-EVM-Interface-Board-B_Mask.gbr, EV2400-EVM-Interface-Board-B_Paste.gbr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]
2020-02-05 EV2400: remove gerber files
    [EV2400-EVM-Interface-Board-B_Cu.gbr, EV2400-EVM-Interface-Board-B_Mask.gbr, EV2400-EVM-Interface-Board-B_Paste.gbr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]
2025-03-11 Update kikad files
    [EV2400-EVM-Interface-2.kicad_sch, EV2400-EVM-Interface-2.sch, EV2400-EVM-Interface-3.kicad_sch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]
2025-09-09 Update hardware files to v4.2
    [AA-PI-V4-Display-Board-BananapiM2M-Battery-Pack.kicad_sch, AA-PI-V4-Display-Board-BananapiM2M-LCD-CTP.kicad_sch, AA-PI-V4-Display-Board-BananapiM2M-RTC.kicad_s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]
2025-09-09 Update EV2400 kicad files
    [AA-PI-V3_0-Radio-Board.dsn, AA-PI-V3_0-Radio-Board.kicad_pcb, AA-PI-V3_0-Radio-Board.sch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]
2025-12-10 Updated to v4.3
    [AA-PI-V4-Display-Board-BananapiM2M-Battery-Pack.kicad_sch, AA-PI-V4-Display-Board-BananapiM2M-LCD-CTP.kicad_sch, AA-PI-V4-Display-Board-BananapiM2M-RTC.kicad_s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]
2026-02-07 Some code cleanup in antenna-analyzer project
2026-03-18 Add docs & readme for bq34z100-g1 setup
    [config.txt, roomtemp_rel_dis_rel.csv]
2026-03-18 Update battery readme
2026-03-19 Add notes about dynamic rebound into the battery README
2026-06-29 Planned updates: radio board design files
    [AA-PI-V4-Radio-Board.kicad_pcb, AA-PI-V4-Radio-Board.kicad_sch]
2026-06-29 Planned updates: display board design files
    [AA-PI-V4-Display-Board-BananapiM2M-Battery-Pack.kicad_sch, AA-PI-V4-Display-Board-BananapiM2M-LCD-CTP.kicad_sch, AA-PI-V4-Display-Board-BananapiM2M-RTC.kicad_s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]
2026-07-24 antenna-analyzer: planned updates
2026-07-29 display board design files: planned updates
    [AA-PI-V4-Display-Board-BananapiM2M.kicad_pcb]

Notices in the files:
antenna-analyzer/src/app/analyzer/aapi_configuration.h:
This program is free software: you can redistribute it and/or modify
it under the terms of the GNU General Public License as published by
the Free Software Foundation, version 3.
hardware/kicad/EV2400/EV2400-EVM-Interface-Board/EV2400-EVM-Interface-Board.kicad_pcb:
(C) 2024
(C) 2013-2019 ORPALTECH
